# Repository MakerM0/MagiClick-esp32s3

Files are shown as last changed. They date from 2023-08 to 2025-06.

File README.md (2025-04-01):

<p align="center">
    <br>
    
    <br>
</p>
<p align="center">   
    
      
</p>

https://github.com/user-attachments/assets/02206fc1-4ecb-459a-b24e-a9fd3fc22468

# MagiClick S3

This is a versatile, single-button keyboard based on the ESP32-S3 microcontroller, featuring a 0.85-inch color display and customizable functionality, perfect for educational purposes, macro keyboard creation, and desktop decoration.It supports multiple programming languages.

# Specifications

- **Dispaly**: 0.85-inch RGB, 128x128 resolution
- **MCU**: ESP32-S3 , Wi-Fi & BLE
- Main operation via central mechanical buttons, with auxiliary buttons on the sides
- Pluggable mechanical switch design, choice of silent or other types
- speaker
- motion sensor
- Expansion port 
- USB Type-C interface
- Reset button at the bottom
-  RGB LEDs
- more

# Purchase

[Browse products ](https://www.elecrow.com/store/MakerM0)

<a href="https://www.pcbway.com/project/shareproject/MagiClick_S3_Single_506b8396.html">PCB from PCBWay</a>

# Hardware 



| Version | |
| :---: | :---: |
| | |
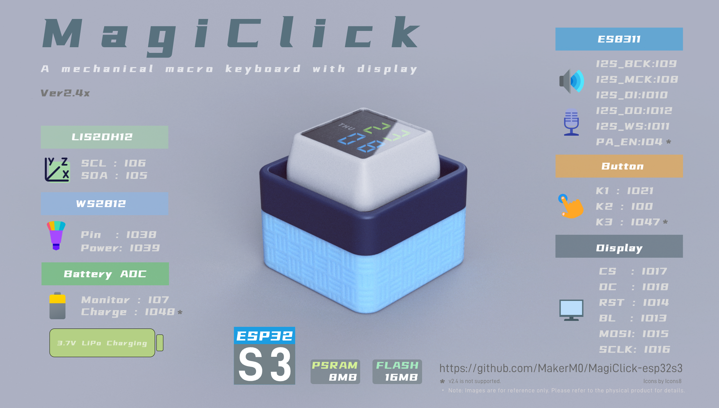
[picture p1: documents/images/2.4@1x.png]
| [2.4](hardware)  |  |
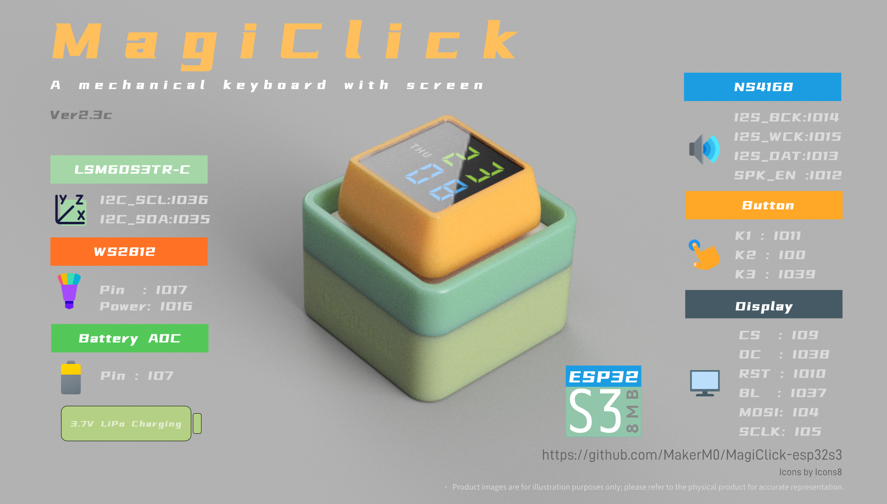
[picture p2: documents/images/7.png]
| [2.3c](hardware)  |  |
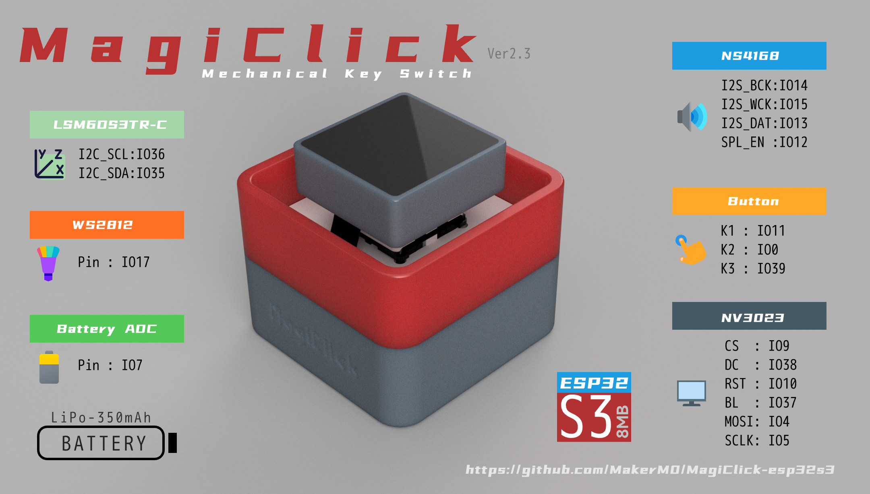
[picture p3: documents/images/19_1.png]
| [2.3b ](hardware) |  |
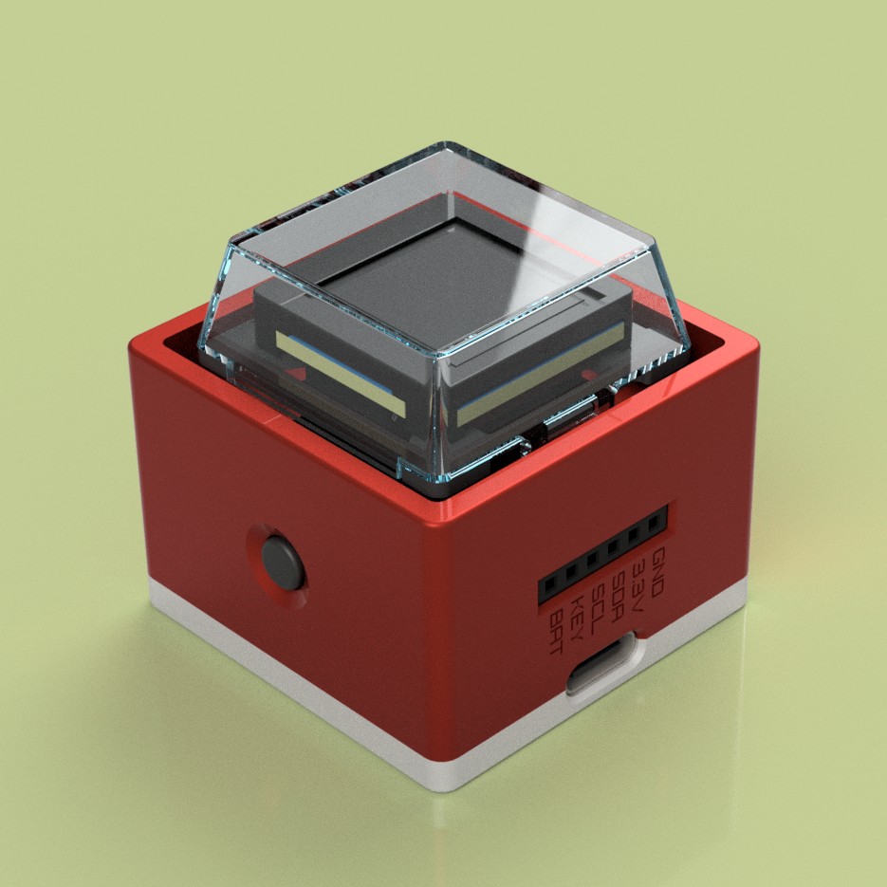
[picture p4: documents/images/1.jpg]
| [2.0](hardware) |  |
| | |

### Difference 

| | v2.0 | v2.3 | v2.4 |
| --- | :---: | :---: | :---: |
| Supported MCU or Module | ESP32-S3-MINI-1-N4R2 or ESP32-S3-MINI-1-N8 | ESP32-S3FN8 | ESP32-S3R8 |
| FLASH | 4MB or 8MB | 8MB | 16MB |
| PSRAM | 2MB or ❌ | ❌ | 8MB |
| Display Driver | GC9107 | NV3023 | NV3023 |
| | GC9107 | NV3023 | NV3023 |
| Battery(with a protection circuit board) | 801230 | 602025 or 802025 | 602025 |
| |  | | |
| Keyboard switch |  |  |  |
| Audio | max98357 | ns4168 | es8311 |
| Microphone | ❌ | ❌ | 1x |
| Motion Sensor | lsm6ds3tr-c | lsm6ds3tr-c | lis2dh12 |

# Software

Supports development using Arduino, CircuitPython, and MicroPython.

The "software" and "firmware" folders in this repository primarily contains the source code related to the hardware version 2.0. 

When you update the circuitpython firmware of the 2.0 hardware to version 9.x, the contents of the 2.3 software [here](https://github.com/MakerM0/MagiClick-S3-Single) folder can then be used by the 2.0 hardware.

For version 2.3, please click  [here](https://github.com/MakerM0/MagiClick-S3-Single).

### Guide

1. Use the Flash Download Tool to burn the Combined .bin in the Firmware folder to the board
2. After rebooting, Then copy the **.uf2** file to a USB stick
3. After rebooting, copy the contents of the softerware folder to the displayed USB stick

 [help](documents/如何下载固件.pdf) 

##### Settings.toml 

modify your wifi information, know the weather key (need to go to the official website to apply) and city

The main button is used to access the function options

The side button or flip button can exit the current function and return to the home page

##### How to add new features

Add the .py file to the app folder

# Mechanical

#### 3D Printings

Makeronline

- [2.3](https://www.makeronline.com/en/model/magiclick%20macropad%20keyboard%20%E7%A5%9E%E5%A5%87%E6%8C%89%E9%92%AE/113241.html)
- [PACKAGING BOX](https://makeronline.com/en/model/product%20packaging%20box/48433.html)
- [PACKAGING BOX_2](https://makeronline.com/en/model/product%20packaging%20box/48433.html)

Makerworld

- [2.0](https://makerworld.com/zh/models/404976#profileId-306794)
- [2.3](https://makerworld.com/zh/models/440612#profileId-346290)
- [2.3](https://makerworld.com/zh/models/584488#profileId-505582)

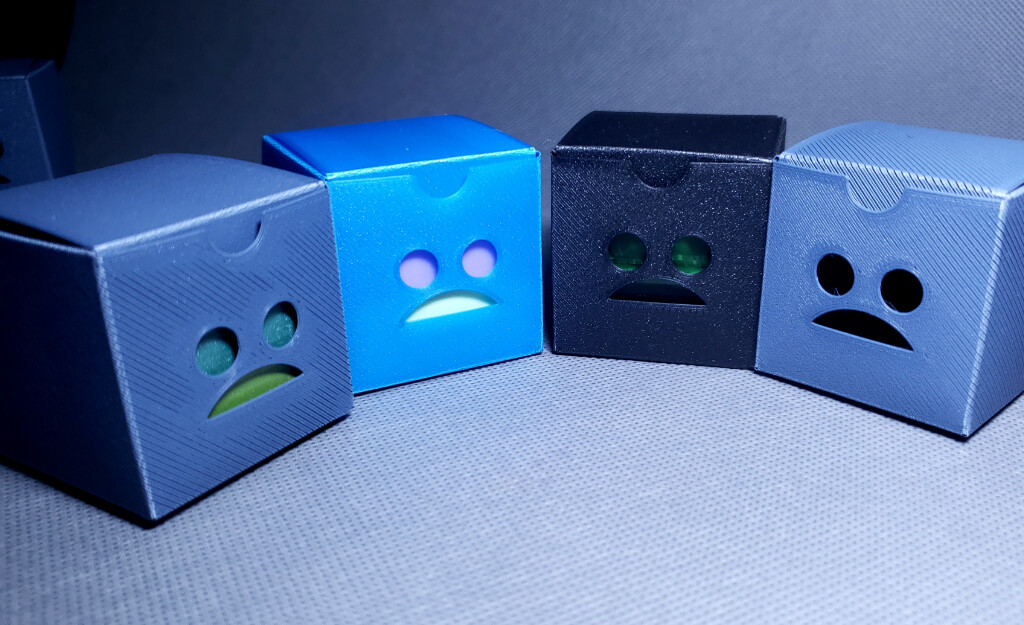
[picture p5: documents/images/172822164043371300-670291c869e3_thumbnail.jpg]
172822164043371300-670291c869e3_thumbnail


## How to contribute

Please use PR to submit contributions

In the **thirdparty** folder, create a project folder according to your own content, the naming needs to be intuitive and easy to understand, and the open source license should be added according to your own wishes

Please add a summary of the contributions in the file **contributer.md**, Add it at the end

## Images

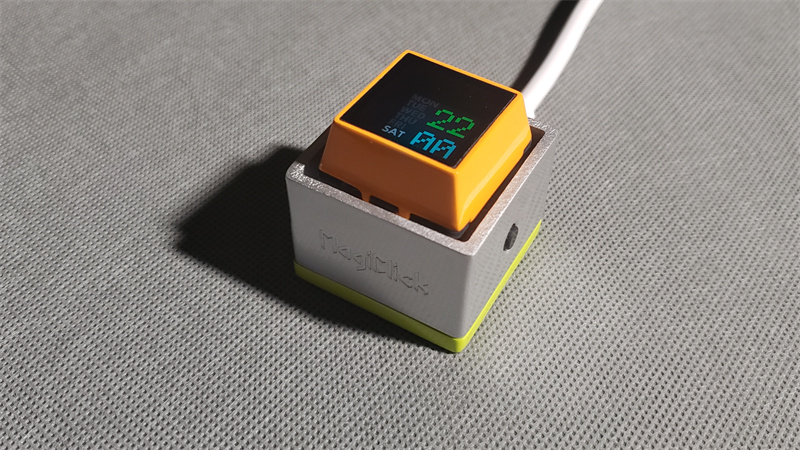
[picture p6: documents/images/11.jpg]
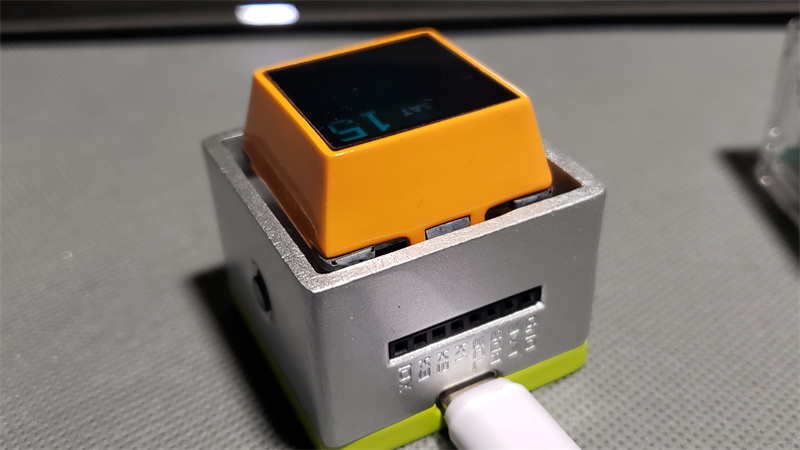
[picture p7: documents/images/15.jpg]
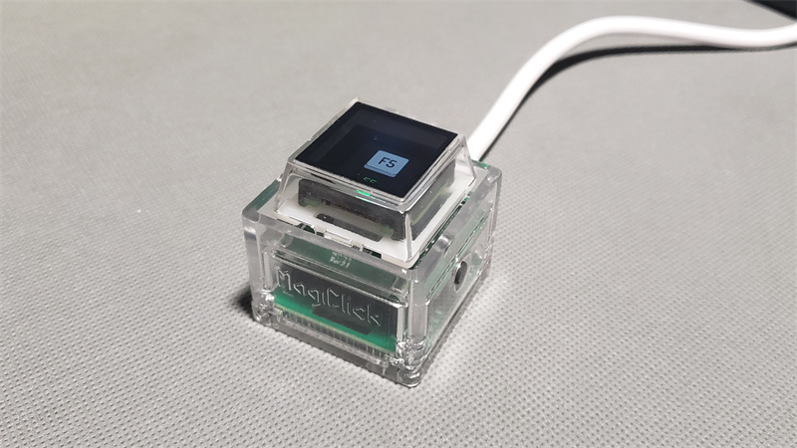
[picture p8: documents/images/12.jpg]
|  |  |  |
| --- | --- | --- |
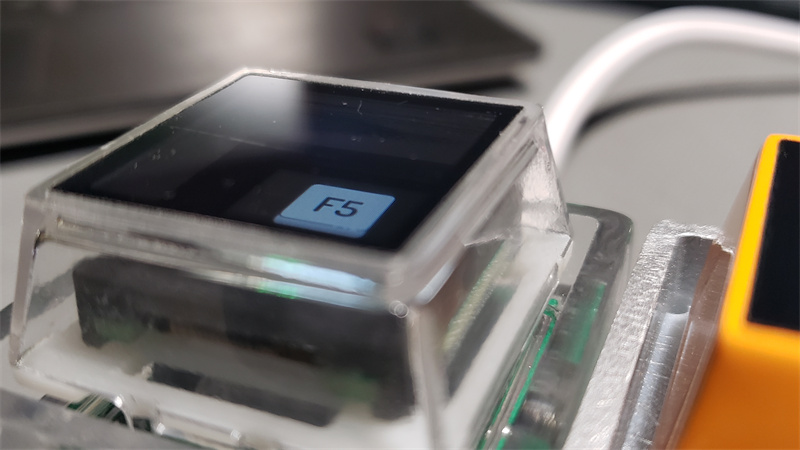
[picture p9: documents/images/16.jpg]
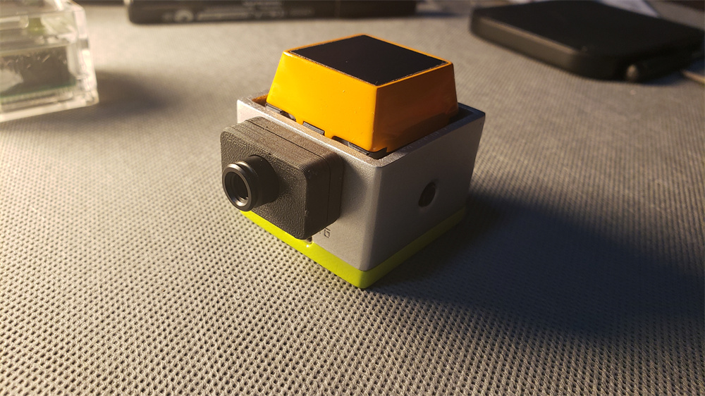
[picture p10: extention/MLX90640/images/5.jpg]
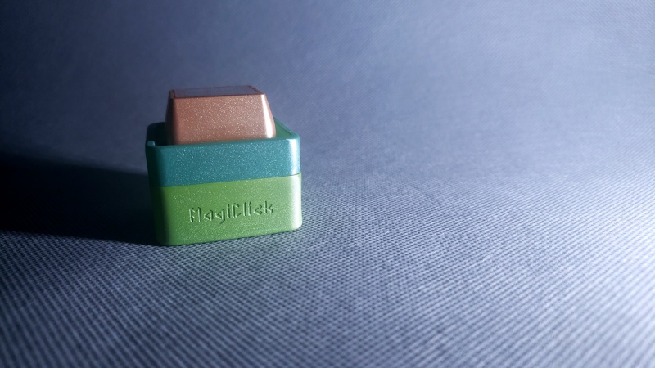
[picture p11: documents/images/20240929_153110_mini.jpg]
20240929_153110_mini
|  |  |  |
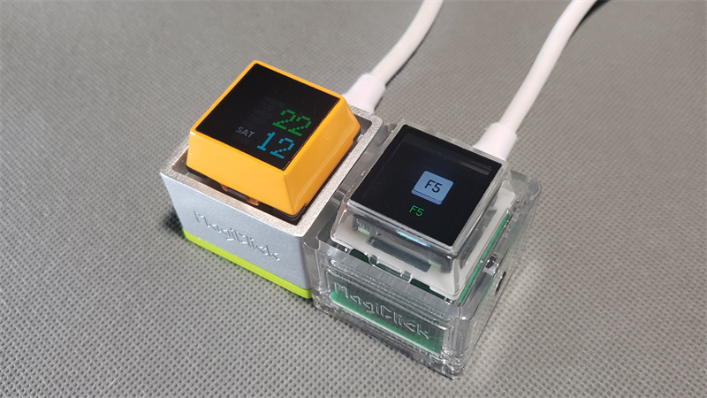
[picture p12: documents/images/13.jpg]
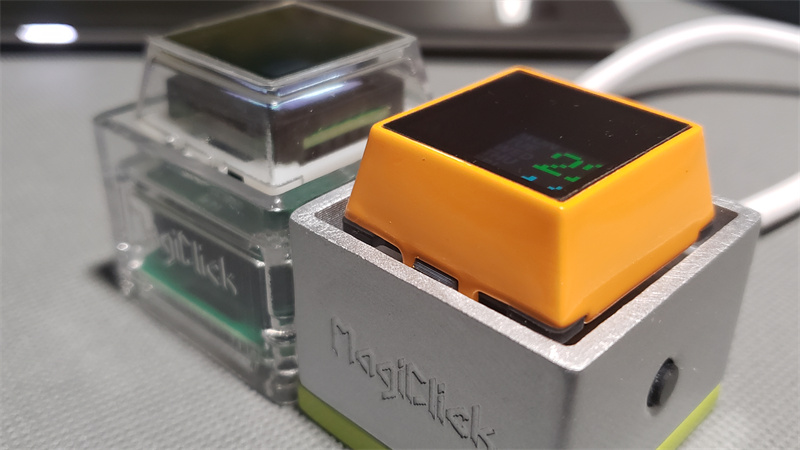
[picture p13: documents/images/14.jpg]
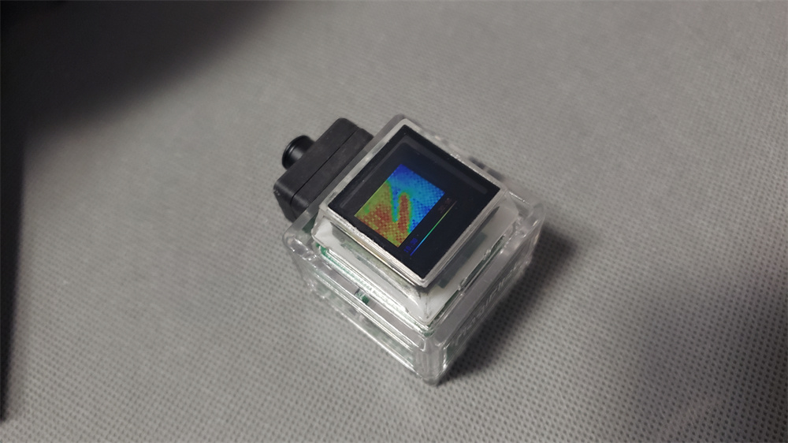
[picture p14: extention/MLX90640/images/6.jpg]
|  |  |  |
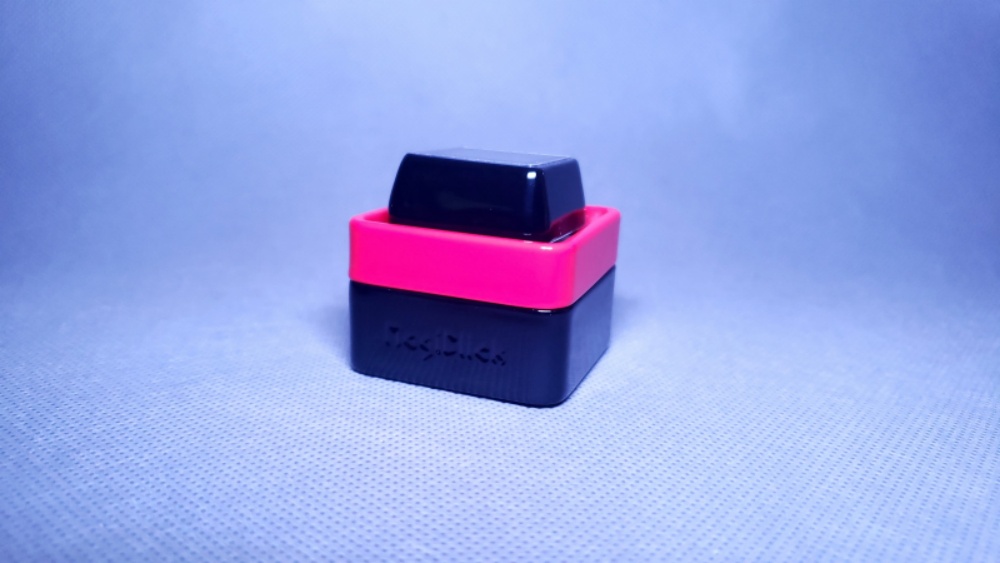
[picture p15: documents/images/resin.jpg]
resin
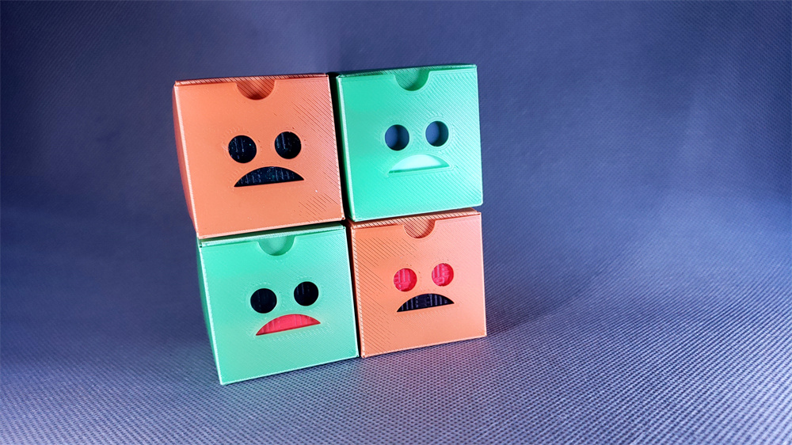
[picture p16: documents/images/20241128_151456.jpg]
| 172822164043371300-670291c869e3_thumbnail |  |  |
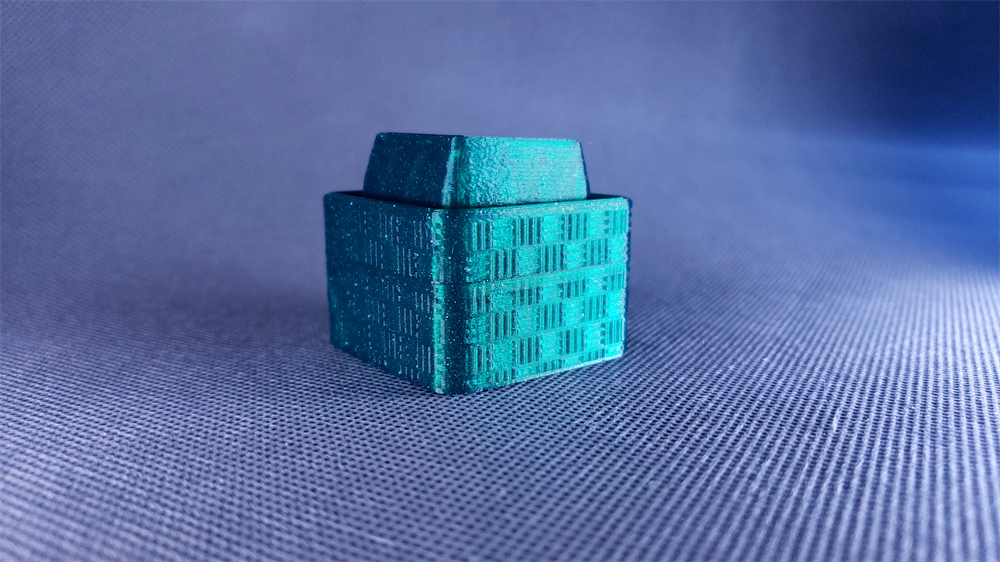
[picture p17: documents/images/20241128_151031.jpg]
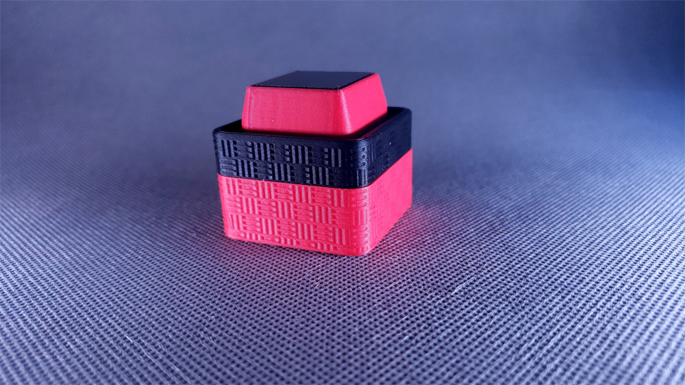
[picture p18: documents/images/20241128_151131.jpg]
|  |  | |

# Extra

The most icons is from https://icons8.com/.

Other resource files come from the internet. 

If there are copyright issues involved, please contact me to delete them.

# License

(documents/hardware/mechanical)[Creative Commons — Attribution-NonCommercial-ShareAlike 4.0 International — CC BY-NC-SA 4.0](https://creativecommons.org/licenses/by-nc-sa/4.0/)

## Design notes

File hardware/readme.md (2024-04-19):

## 2.3b

- The power path has been modified, and the switch can fully control the power supply on and off

- The 0402 package is fully adopted, which greatly reduces the total PCB area

- The main controller replaces the original module in the form of a chip

- The audio chip was replaced

**Click on the image below and you can make it directly**

<a href="https://www.pcbway.com/project/shareproject/MagiClick_S3_Single_506b8396.html">PCB from PCBWay</a>

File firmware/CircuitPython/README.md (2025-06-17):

# 1

burn the bin file from the bootloader to address 0

# 2

restart the device and drag the uf2 file into the USB drive

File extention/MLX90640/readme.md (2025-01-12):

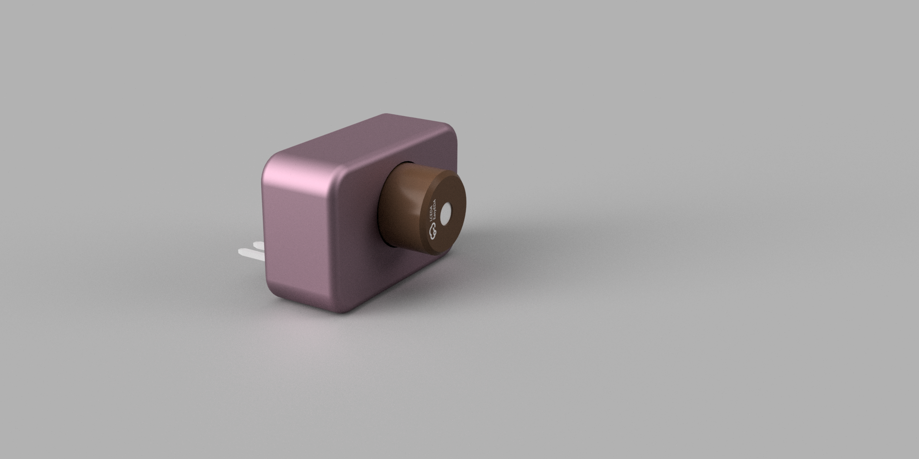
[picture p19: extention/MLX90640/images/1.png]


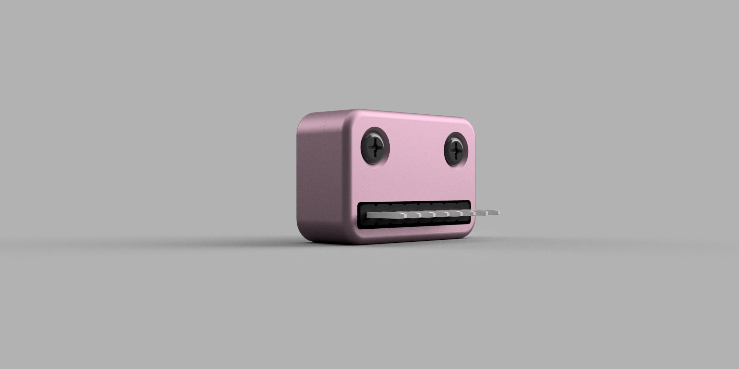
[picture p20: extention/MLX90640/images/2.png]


# MLX90640

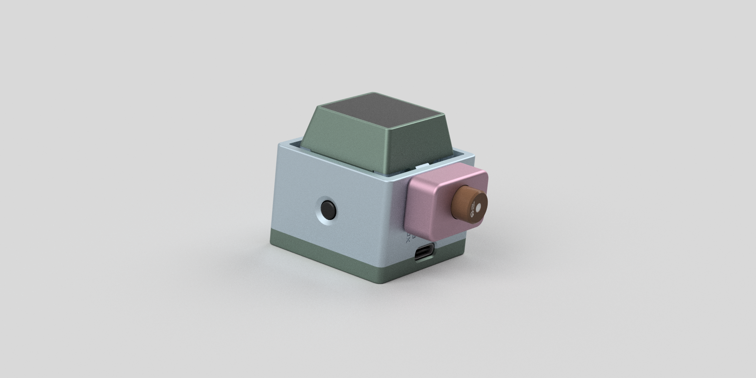
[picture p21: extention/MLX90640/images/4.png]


## SUPPORT

- MagiClick 2.0 PCB

## BOM

| No.  | Quantity | Designator | Footprint | Manufacturer Part | Manufacturer | Supplier | Supplier Part | Value | Comment | JLCPCB Part Class |
| ---- | --- | --- | --- | --- | --- | --- | --- | ----- | --- | --- |
| 1 | 1 | C1 | C0603 | CL10A106KP8NNNC | SAMSUNG(三星) | LCSC | C19702 | 10uF  | 10uF | Basic Part |
| 2 | 1 | C2 | C0603 | 0603B104K500NT | FH(风华) | LCSC | C30926 | 100nF | 100nF | 扩展库 |
| 3 | 1 | U1 | TO-39-4_MELEXIS_MLX90640 | **MLX90640ESF-BAB-000-TU** | Melexis(比利时迈来芯) | LCSC | C488251 | | MLX90640ESF-BAB-000-TU | Extended Part |
| 4 | 1 | U203 | HDR-TH_8P-P2.54-V-M | PZ254V-11-08P | XFCN(兴飞) | LCSC | C492407 | | PZ254V-11-08P | Extended Part |

## PCB

1.6mm

## 304不锈钢自攻螺丝十字沉头螺丝

M2*8   2

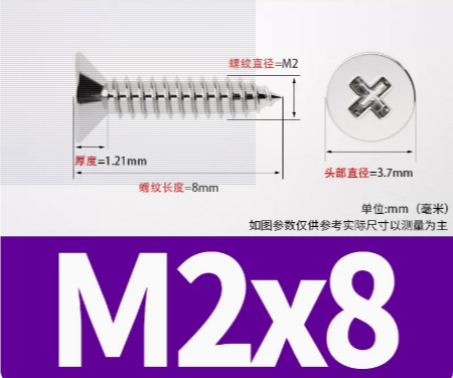
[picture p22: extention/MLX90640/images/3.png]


## images





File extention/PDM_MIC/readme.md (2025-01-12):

# PDM_MIC

Due to the limitations of the current 2.3 version hardware, in order to use this module, it is necessary to remove the motion sensor and its associated components.

## SUPPORT

- MagiClick 2.3c PCB

## BOM

-  [BOM.xlsx](BOM.xlsx) 
- JS05B-04P-030-3-4

## PCB

thickness: 1.6mm

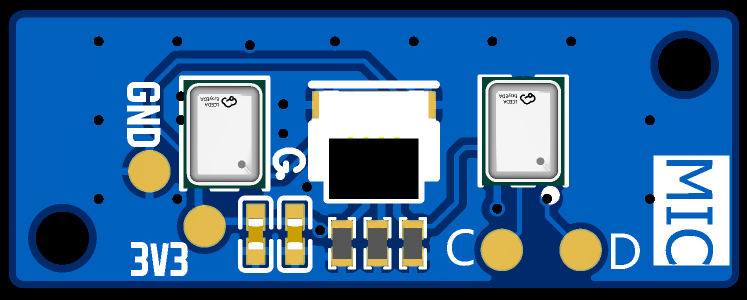
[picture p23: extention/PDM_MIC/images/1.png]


## GUIDE

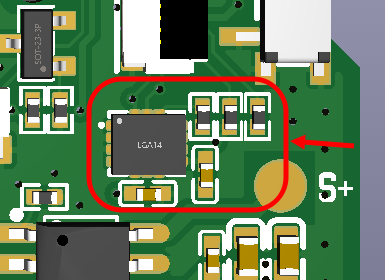
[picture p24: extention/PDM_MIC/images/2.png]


Remove the components within the red box.

## images

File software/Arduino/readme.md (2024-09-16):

# Ported Source

### esp32_gfx_dino

[wasm-embedded/arduino/esp32_gfx_dino at master · wuhanstudio/wasm-embedded (github.com)](https://github.com/wuhanstudio/wasm-embedded/tree/master/arduino/esp32_gfx_dino)





### TinyFlap

Code ported from [soelvberg/TinyFlap: A Flappy Bird like game for micro controller with 128x128 TFT display. (github.com)](https://github.com/soelvberg/TinyFlap)

Please use [PlatformIO](https://platformio.org/platformio-ide) for compilation and development

Flashing this firmware may overwrite the previous python file, please make a backup

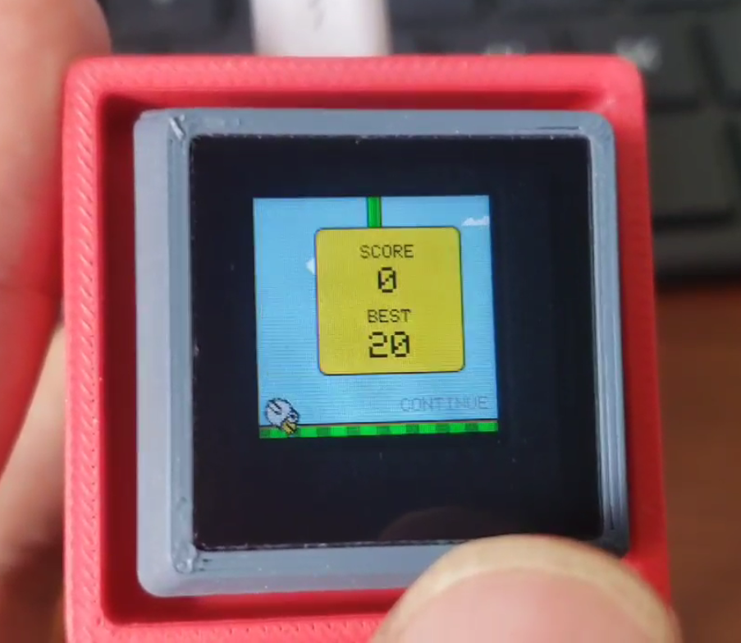
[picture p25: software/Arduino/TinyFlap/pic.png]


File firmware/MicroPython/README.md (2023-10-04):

# Thanks to the following friends for their contributions

### The contents under the jd3096 folder are from [jd3096-mpy](https://github.com/jd3096-mpy)

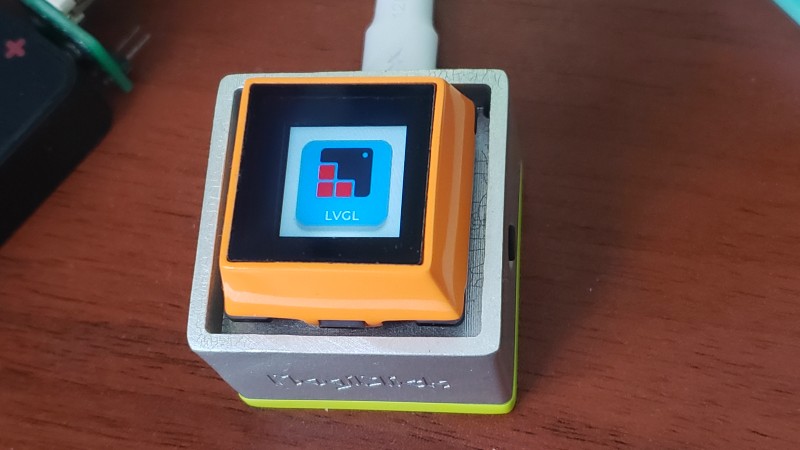
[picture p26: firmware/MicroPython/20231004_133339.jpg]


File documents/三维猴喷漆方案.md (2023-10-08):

# 使用LEDO 6060 材质官方喷漆

### 底盖

喷漆-亮光-浅绿色  

### 外壳

喷漆-亮光-银色

### 玻璃罩

喷漆-亮光-橙色

# EVA配色

绿色 （100，181，26）

紫色（132，85，165）

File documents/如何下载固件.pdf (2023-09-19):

# 如何给神奇按钮下载固件

https://github.com/MakerM0/MagiClick-esp32s3

# 1、进入esp32-S3芯片的下载模式

在插入usb的情况下，按住左侧按钮不放，然后使用镊子按下底部的复位按钮，然后会发现电脑的设备 管理器出现了串口（记住自己的端口号），此时可以松开左侧按键

# 2、烧写bootload

使用乐鑫官方的flash download tool工具，可从官网或github仓库的tool文件夹找到

按箭头所示操作即可

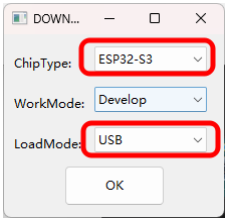
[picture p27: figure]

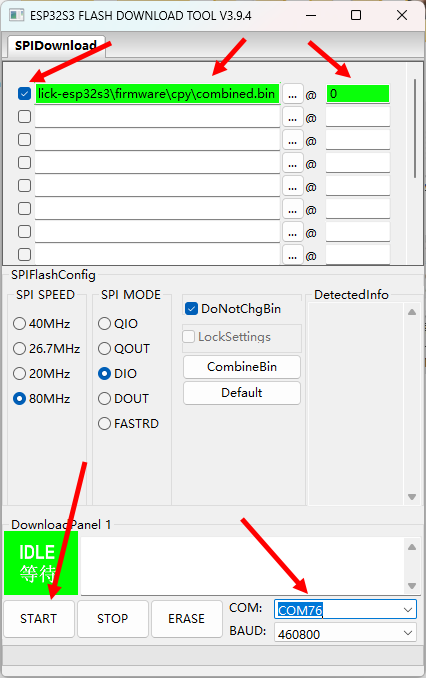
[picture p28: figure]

下载成功后出现

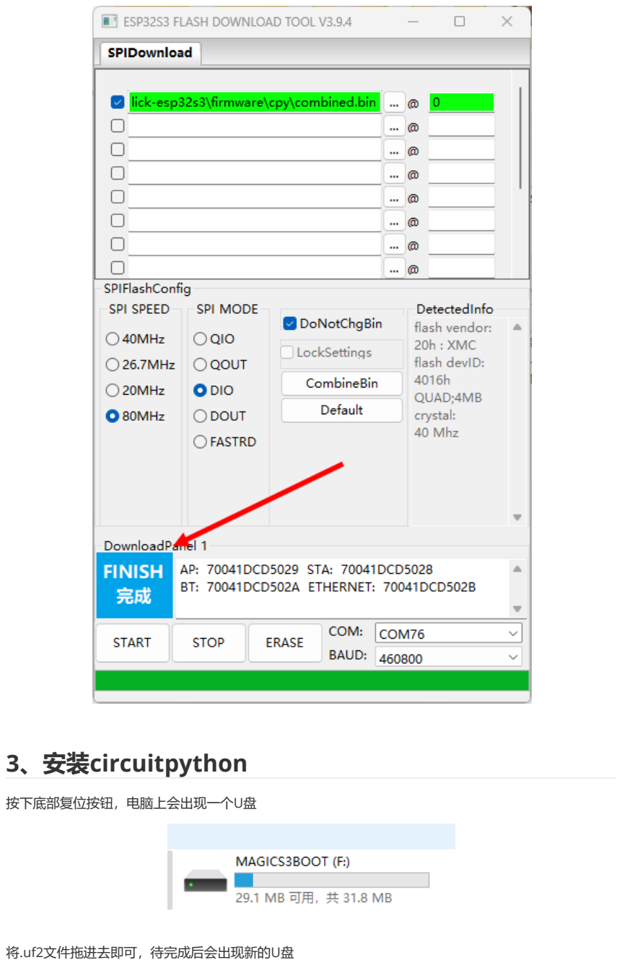
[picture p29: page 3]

# 3、安装circuitpython

按下底部复位按钮，电脑上会出现一个U盘

将.uf2文件拖进去即可，待完成后会出现新的U盘

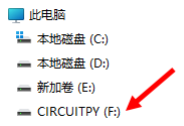
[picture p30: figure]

# 4、复制软件包到U盘

将github上software里面的内容复制到U盘即可完成功能更新

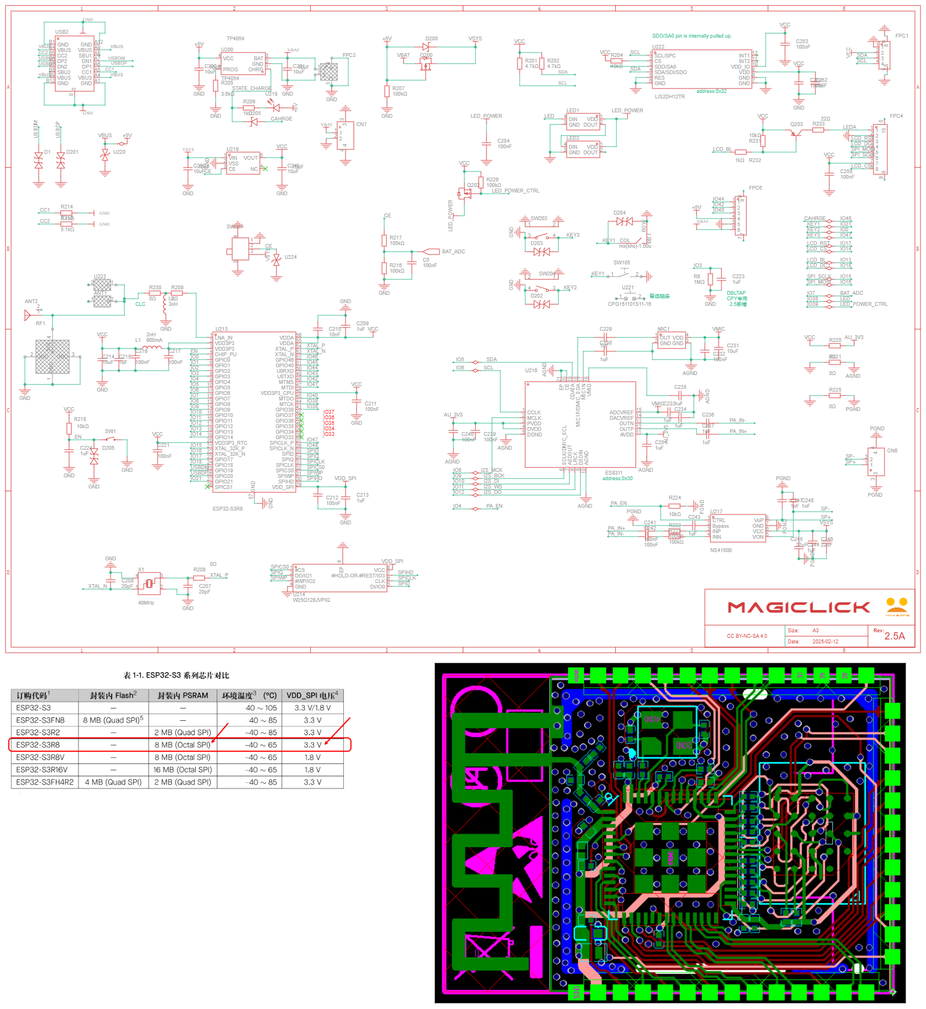
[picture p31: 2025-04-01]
hardware/2.5/SCH_2.5A.png

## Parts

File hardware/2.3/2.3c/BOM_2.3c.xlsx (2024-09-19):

Comment | Designator | Footprint | Supplier Part | Quantity | Description | Layer | JLCPCB Part Class
100nF | C5,C9,C202,C203,C211,C212,C216,C217,C221 | C0402 | C1525 | 9 | 容值:100nF;精度:±10%;额定电压:16V;材质(温度系数):X7R; | B | Basic Part,基础库
10uF | C200,C201,C214 | C0603 | C19702 | 3 | 容值:10uF;精度:±10%;额定电压:10V;材质(温度系数):X5R; | B | Basic Part
1uF | C204,C205 | C0603 | C15849 | 2 | 温度系数:X5R;精度:±10%;额定电压:50V;容值:1uF; | B | Basic Part
20pF | C207,C208 | C0402 | C1554 | 2 | 容值:20pF;精度:±5%;额定电压:50V;材质(温度系数):C0G; | B | 基础库
1uF | C209,C213,C215,C223,C224,C228 | C0402 | C52923 | 6 | 容值:1uF;精度:±10%;额定电压:25V;材质(温度系数):X5R; | B | 基础库
10nF | C210 | C0402 | C15195 | 1 | 容值:10nF;精度:±10%;额定电压:50V;材质(温度系数):X7R; | B | 基础库
22uF | C226,C227 | C0603 | C59461 | 2 | 容值:22uF;精度:±20%;额定电压:6.3V;材质(温度系数):X5R; | B | Basic Part
HC-FPC-05-09-12RLTAG | CN4 | CONN-SMD_12P-P0.50_HCTL_HC-FPC-05-09-12RLTAG | C5213751 | 1 | 间距:0.5mm;触点数量:12P;锁定特性:翻盖式;安装类型:卧贴;触点类型:下接; | B | 扩展库
PESDNC2FD3V3B | D1,D201,D202,D203,D204 | DFN1006-2L-BI | C492728 | 5 |  | B | 扩展库
1N5819WS | D200 | SOD-323_L1.8-W1.3-LS2.5-RD | C191023 | 1 | 直流反向耐压(Vr):40V;平均整流电流(Io):1A;正向压降(Vf):600mV@1A; | B | Basic Part
HC-FPC-05-09-4RLTAG | FPC1 | FPC-SMD_4P-P0.50_HC-FPC-05-09-4RLTAG | C5213746 | 1 | 锁定特性:翻盖式;触点类型:双侧触点/上下接;触点数量:4P;间距:0.5mm;安装类型:卧贴;工作温度范围:-55℃~+85℃;焊接温度(最大值):-; | B | 扩展库
2nH | L1 | L0402 | C18216 | 1 | 电感值:2nH;精度:-;额定电流:900mA;饱和电流(Isat):-;直流电阻(DCR):90mΩ; | B | Extended Part
XL-3216SURC-FB | LED201 | LED1206-RD_RED_LTST-C230CKT | C3646938 | 1 | 灯头类型:-;发光颜色:红色;正向电压(VF):1.8V~2.1V;功率:60mW;正向电流:5mA;主波长:617nm~627nm;二极管配置:-;透镜颜色:透明透镜;色温:-;发光强度:100mcd~120mcd;发光角度:120°;载带方式:反贴;工作温度:-; | B | 扩展库
SK6812MINI-E | LED202 | LED-SMD_L3.2-W2.8-TR | C5149201 | 1 |  | B | Extended Part
CPG151101S11-16 | MX1 | cherrymx(khs)-1.00u | C5156480 | 1 | 轴类型:-;工作电压:2V~12V;操作力:-;触底力:-;触发行程:-;总行程:-;针脚数:-;机械寿命:-;工作温度:-; | B | Extended Part
AO3401A | Q200 | SOT-23_L2.9-W1.3-P1.90-LS2.4-BR | C15127 | 1 | 类型:P沟道;漏源电压(Vdss):30V;连续漏极电流(Id):4A;功率(Pd):1.4W;导通电阻(RDS(on)@Vgs,Id):44mΩ@10V,4.3A;阈值电压(Vgs(th)@Id):1.3V@250A; | B | Basic Part
SS8050 | Q201 | SOT-23-3_L2.9-W1.3-P1.90-LS2.4-BR | C2150 | 1 | 集电极电流(Ic):1.5A;功率(Pd):300mW;晶体管类型:NPN;集射极击穿电压(Vceo):25V; | B | BasicPart
1MΩ | R8 | R0402 | C26083 | 1 | 电阻类型:厚膜电阻;阻值:1MΩ;精度:±1%;功率:62.5mW;最大工作电压:50V;温度系数:±100ppm/℃; | B | Basic Part
10kΩ | R201,R202,R204,R211,R218 | R0402 | C25744 | 5 | 电阻类型:厚膜电阻;阻值:10kΩ;精度:±1%;功率:62.5mW;最大工作电压:50V;温度系数:±100ppm/℃; | B | Basic Part
5.1kΩ | R205,R214,R215 | R0402 | C25905 | 3 | 电阻类型:厚膜电阻;阻值:5.1kΩ;精度:±1%;功率:62.5mW;最大工作电压:50V;温度系数:±100ppm/℃;,阻值:5.1kΩ;精度:±1%;功率:62.5mW;温度系数:±100ppm/℃;电阻类型:厚膜电阻; | B | Basic Part
1kΩ | R206,R212 | R0402 | C11702 | 2 | 电阻类型:厚膜电阻;阻值:1kΩ;精度:±1%;功率:62.5mW;最大工作电压:50V;温度系数:±100ppm/℃; | B | Basic Part
100kΩ | R207,R216,R217,R219 | R0402 | C25741 | 4 | 电阻类型:厚膜电阻;阻值:100kΩ;精度:±1%;功率:62.5mW;最大工作电压:50V;温度系数:±100ppm/℃; | B | Basic Part
0Ω | R208,R209 | R0402 | C17168 | 2 | 电阻类型:厚膜电阻;阻值:0Ω;精度:±1%;功率:62.5mW;最大工作电压:50V;温度系数:±800ppm/℃; | B | 基础库
22Ω | R213 | R0402 | C25092 | 1 | 电阻类型:厚膜电阻;阻值:22Ω;精度:±1%;功率:62.5mW;最大工作电压:50V;温度系数:±100ppm/℃; | B | Basic Part
TSA010A2026B | SW1 | SW-SMD_L4.0-W3.0-LS5.0 | C2888420 | 1 | 触点电流:50mA;额定电压(AC):-;额定电压(DC):12V;安装方式:立贴;按钮形状:圆形按钮;开关长度:3.9mm;开关宽度:3mm;开关高度:2mm; | B | Extended Part
TS24CA 250gf 013 | SW203,SW204 | SW-SMD_L4.7-W3.5-P3.35-EH | C5373430 | 2 | 电路结构:单刀单掷;按钮形状:矩形按钮;作用力:250gf;安装方式:卧贴;开关长度:4.55mm;开关宽度:1.8mm;开关高度:3.5mm;带支架:不带;触点电流:50mA;额定电压(AC):-;额定电压(DC):12V;额定功率:0.6W;绝缘电阻:100MΩ;带灯:无;机械寿命:3万次; | B | 扩展库
MSK12C02 | SW205 | SW-TH_MSK12C02 | C431540 | 1 | 电路结构:单刀双掷;安装方式:卧贴;开关颜色:-;额定电流(DC):50mA;额定电压(DC):12V;额定电流(AC):-;额定电压(AC):-;机械寿命:1万次; | B | 扩展库
TP4054 | U200 | SOT-23-5_L2.9-W1.6-P0.95-LS2.8-BR | C5381776 | 1 | 电源电压:4V~9V;最大充电电流:800mA;电池类型:锂离子/聚合物;电池节数:1; | B | Extended Part
LSM6DS3TR-C | U201 | LGA-14_L3.0-W2.5-P0.50-TL | C967633 | 1 |  | B | Extended Part
AP2112K-3.3TRG1 | U202 | SOT-25-5_L2.9-W1.6-P0.95-LS2.8-BL | C51118 | 1 | 输出类型:固定;输出极性:正;最大输入电压:6V;输出电压:3.3V;输出电流:600mA;电源纹波抑制比(PSRR):65dB@(100Hz,1kHz); | B | Extended Part
ESP32-S3FN8 | U205 | QFN-56_L7.0-W7.0-P0.40-TL-EP4.0 | C2913196 | 1 |  | B | 扩展库
NS4168 | U207 | ESOP-8_L4.9-W3.9-P1.27-LS6.0-BL-EP-1 | C9900042517 | 1 |  | B
AN2051-245 | U208 | ANT2051 | C99727 | 1 | 小体积，高增益，WIFI，蓝牙，zigBee 2.4G天线 | B | Extended Part
USB-TYPE-C-018 | USB2 | usb-c_smd-type-c-31-m-12 | C2927038 | 1 | 连接器类型:Type-C;标准:-;公母:母座;触点数量:16;端口数量:1;安装方式:卧贴;额定电流 - 电源:3A;工作温度范围:-25~+85; | B | Extended Part
40MHz | X1 | CRYSTAL-SMD_4P-L3.2-W2.5-BL | C5444549 | 1 | 晶振类型:贴片晶振;频率:40MHz;常温频差:±10ppm;外接负载电容:15pF;频率稳定度(全温):±20ppm; | B | Extended Part

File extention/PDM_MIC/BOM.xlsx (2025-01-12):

Comment | Designator | Footprint | Supplier Part | Quantity | Manufacturer | Manufacturer Part
1uF | C106 | C0402 | C52923 | 1 | SAMSUNG(三星) | CL05A105KA5NQNC
100nF | C107 | C0402 | C1525 | 1 | SAMSUNG(三星) | CL05B104KO5NNNC
PESDNC2FD3V3B | D1,D2,D3 | DFN1006-2L-BI | C492728 | 3 | Prisemi(芯导) | PESDNC2FD3V3B
HC-FPC-05-09-4RLTAG | FPC1 | FPC-SMD_4P-P0.50_HC-FPC-05-09-4RLTAG | C5213746 | 1 | HCTL(华灿天禄) | HC-FPC-05-09-4RLTAG
MMICT390200012 | MIC2 | MIC-SMD_5P-L3.5-W2.7-TL_MMICT390200012 | C3171752 | 1 | TDK InvenSense(应美盛) | MMICT390200012

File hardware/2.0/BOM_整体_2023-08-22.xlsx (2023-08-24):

No. | Quantity | Designator | Footprint | Manufacturer Part | Manufacturer | Supplier | Supplier Part | Value | Comment | JLCPCB Part Class
1 | 5 | C1,C6,C7,C200,C201 | C0603 | CL10A106KP8NNNC | SAMSUNG(三星) | LCSC | C19702 | 10uF | 10uF | Basic Part
2 | 6 | C2,C5,C9,C202,C203,C300 | C0603 | CC0603KRX7R9BB104 | YAGEO(国巨) | LCSC | C14663 | 100nF | 100nF | Basic Part
3 | 6 | C8,C10,C11,C204,C205,C301 | C0603 | CL10A105KB8NNNC | SAMSUNG(三星) | LCSC | C15849 | 1uF | 1uF | Basic Part
4 | 1 | D200 | SOD-323_L1.8-W1.3-LS2.5-RD | 1N5819WS | Hottech(合科泰) | LCSC | C191023 |  | 1N5819WS | Basic Part
5 | 6 | H1,H2,H3,H4,H200,H201 | HDR-TH_4P-P2.54-V-F | 2.54-1*4P母 | BOOMELE(博穆精密) | LCSC | C2718488 |  | 2.54-1*4P母 | Extended Part
6 | 6 | H202,H203,H204,H205,H300,H301 | HDR-TH_4P-P2.54-V-M | DZ254R-11-04-63 | DEALON(德艺隆) | LCSC | C2935910 |  | DZ254R-11-04-63 | Extended Part
7 | 2 | LED1,LED2 | LED-SMD_4P-L1.6-W1.5_XL-1615RGBC-WS2812B | XL-1615RGBC-WS2812B | XINGLIGHT(成兴光) | LCSC | C5349954 |  | XL-1615RGBC-WS2812B | Extended Part
8 | 1 | Q200 | SOT-23_L2.9-W1.3-P1.90-LS2.4-BR | AO3401A | AOS | LCSC | C15127 |  | AO3401A | Basic Part
9 | 1 | Q300 | SOT-23-3_L2.9-W1.3-P1.90-LS2.4-BR | SS8050 | CJ（江苏长电/长晶） | LCSC | C2150 |  | SS8050 | BasicPart
10 | 1 | R1 | R0603 | WR06X6343FTL | Walsin(华新科) | LCSC | C334826 | 634kΩ | 634kΩ | Extended Part
11 | 2 | R2,R207 | R0603 | 0603WAF1003T5E | UNI-ROYAL(厚声) | LCSC | C25803 | 100kΩ | 100kΩ | Basic Part
12 | 2 | R3,R4 | R0603 | 0603WAF5101T5E | UNI-ROYAL(厚声) | LCSC | C23186 | 5.1kΩ | 5.1kΩ | Basic Part
13 | 2 | R5,R6 | R0603 | 0603WAF2003T5E | UNI-ROYAL(厚声) | LCSC | C25811 | 200kΩ | 200kΩ | Basic Part
14 | 7 | R7,R201,R202,R203,R204,R205,R302 | R0603 | 0603WAF1002T5E | UNI-ROYAL(厚声) | LCSC | C25804 | 10kΩ | 10kΩ | Basic Part
15 | 1 | R8 | R0603 | 0603WAF1004T5E | UNI-ROYAL(厚声) | LCSC | C22935 | 1MΩ | 1MΩ | 基础库
16 | 2 | R206,R301 | R0603 | 0603WAF1001T5E | UNI-ROYAL(厚声) | LCSC | C21190 | 1kΩ | 1kΩ | Basic Part
17 | 1 | R300 | R0603 | 0603WAF200JT5E | UNI-ROYAL(厚声) | LCSC | C22950 | 20Ω | 20Ω | Basic Part
18 | 1 | SW1 | SW-SMD_L4.0-W3.0-LS5.0 | TSA010A2026B | BZCN(博众电气) | LCSC | C2888420 |  | TSA010A2026B | Extended Part
19 | 1 | SW2 | SW-SMD_MS-22D28-G020 | MS-22D28-G020 | G-Switch(品赞) | LCSC | C963205 |  | MS-22D28-G020 | Extended Part
20 | 2 | SW200,SW202 | SW-TH_ST-1109-3-5 | TS-1091B-A4B3-D2 | Yuandi(元迪) | LCSC | C557910 |  | TS-1091B-A4B3-D2 | Extended Part
21 | 1 | SW201 | 凯华矮轴 复合 热插拔 | CPG135001S30 | Kailh(凯华) | LCSC | C5333465 |  | CPG135001S30 | Extended Part
22 | 1 | U1 | TQFN-16_L3.0-W3.0-P0.50-BL-EP1.5 | MAX98357AETE+T | ADI(亚德诺)/MAXIM(美信) | LCSC | C910544 |  | MAX98357AETE+T | Extended Part
23 | 1 | U2 | BULETM-SMD_ESP32-S3-MINI-1-N8 | ESP32-S3-MINI-1-N4R2 | ESPRESSIF(乐鑫) | LCSC | C3013941 |  | ESP32-S3-MINI-1-N4R2 | Extended Part
24 | 1 | U200 | TSOT-23-5_L2.9-W1.6-P0.95-LS2.8-BR | TP4054 | UMW(友台半导体) | LCSC | C668215 |  | TP4054 | Extended Part
25 | 1 | U201 | LGA-14_L3.0-W2.5-P0.50-TL | LSM6DS3TR-C | ST(意法半导体) | LCSC | C967633 |  | LSM6DS3TR-C | Extended Part
26 | 1 | U202 | SOT-25-5_L2.9-W1.6-P0.95-LS2.8-BL | AP2112K-3.3TRG1 | DIODES(美台) | LCSC | C51118 |  | AP2112K-3.3TRG1 | Extended Part
27 | 1 | U203 | HDR-TH_8P-P2.54-H-F-W10.3-N | DW254W-11-08-85 | DEALON(德艺隆) | LCSC | C2935998 |  | DW254W-11-08-85 | Extended Part
28 | 1 | U300 | TFT_0.85inch_128*128 |  |  |  |  |  | 0.85inch-TFT
29 | 1 | USB1 | USB-C-SMD_SHOU_TYPE-C-16P-CB1.6 | TYPE-C 16P CB1.6 073 | SHOU HAN(首韩) | LCSC | C2906290 |  | TYPE-C 16P CB1.6 073 | Extended Part

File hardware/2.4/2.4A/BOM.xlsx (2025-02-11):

Comment | Designator | Footprint | Supplier Part | Quantity | Manufacturer | Manufacturer Part
100nF | C5,C203,C211,C212,C216,C217,C221,C232,C239,C240,C241,C242,C253,C254 | C0402 | C1525 | 14 | SAMSUNG(三星) | CL05B104KO5NNNC
10uF | C200,C201,C214,C231,C249,C250,C252 | C0402 | C2846677 | 7 | FH(风华) | 0402X106M100NT
20pF | C207,C208 | C0402 | C1554 | 2 | FH(风华) | 0402CG200J500NT
1uF | C209,C213,C215,C224,C229,C230,C233,C234,C235,C236,C237,C243,C244,C251 | C0402 | C52923 | 14 | SAMSUNG(三星) | CL05A105KA5NQNC
10nF | C210 | C0402 | C15195 | 1 | SAMSUNG(三星) | CL05B103KB5NNNC
22uF | C245,C246 | C0603 | C59461 | 2 | SAMSUNG(三星) | CL10A226MQ8NRNC
1nF | C247,C248 | C0402 | C1523 | 2 | FH(风华) | 0402B102K500NT
HC-FPC-05-09-12RLTAG | CN4 | CONN-SMD_12P-P0.50_HCTL_HC-FPC-05-09-12RLTAG | C5213751 | 1 | HCTL(华灿天禄) | HC-FPC-05-09-12RLTAG
PESDNC2FD3V3B | D1,D201,D202,D203,D204 | DFN1006-2L-BI | C492728 | 5 | Prisemi(芯导) | PESDNC2FD3V3B
1N5819WS | D200,D205 | SOD-323_L1.8-W1.3-LS2.5-RD | C191023 | 2 | Hottech(合科泰) | 1N5819WS
BSMD0603L-100 | F1 | F0603 | C2757929 | 1 | BHFUSE(佰宏) | BSMD0603L-100
HC-FPC-05-09-4RLTAG | FPC1 | FPC-SMD_4P-P0.50_HC-FPC-05-09-4RLTAG | C5213746 | 1 | HCTL(华灿天禄) | HC-FPC-05-09-4RLTAG
1.25-2PS | FPC2,FPC3 | CONN-SMD_2P-P1.25_DEALON_1.25-2PS | C2904989 | 2 | DEALON(德艺隆) | 1.25-2PS
2nH | L1 | L0402 | C18216 | 1 | muRata(村田) | LQG15HS2N0S02D
SK6805-EC15 | LED4,LED5 | LED-SMD_4P-L1.5-W1.5-BL | C2890035 | 2 | 欧思科光电 | SK6805-EC15
ZTS6216 | MIC1 | MIC-SMD_4P-L2.8-W1.9-P1.84-TL | C481302 | 1 | ZILLTEK(钰太) | ZTS6216
AO3401A | Q200,Q202 | SOT-23_L2.9-W1.3-P1.90-LS2.4-BR | C15127 | 2 | AOS | AO3401A
SS8050 | Q201 | SOT-23-3_L2.9-W1.3-P1.90-LS2.4-BR | C2150 | 1 | CJ（江苏长电/长晶） | SS8050
4.7kΩ | R201,R202 | R0402 | C25900 | 2 | UNI-ROYAL(厚声) | 0402WGF4701TCE
10kΩ | R204,R205,R211,R218,R224 | R0402 | C25744 | 5 | UNI-ROYAL(厚声) | 0402WGF1002TCE
1kΩ | R206,R212 | R0402 | C11702 | 2 | UNI-ROYAL(厚声) | 0402WGF1001TCE
100kΩ | R207,R216,R217,R222,R223,R226 | R0402 | C25741 | 6 | UNI-ROYAL(厚声) | 0402WGF1003TCE
0Ω | R208,R209,R220,R221,R225 | R0402 | C17168 | 5 | UNI-ROYAL(厚声) | 0402WGF0000TCE
22Ω | R213 | R0402 | C25092 | 1 | UNI-ROYAL(厚声) | 0402WGF220JTCE
5.1kΩ | R214,R215 | R0402 | C25905 | 2 | UNI-ROYAL(厚声) | 0402WGF5101TCE
KH-IPEX-K501-29 | RF1 | ANT-SMD_KH-IPEX-K501-29 | C411563 | 1 | kinghelm(金航标) | KH-IPEX-K501-29
TSA010A2026B | SW1 | SW-SMD_L4.0-W3.0-LS5.0 | C2888420 | 1 | BZCN(博众电气) | TSA010A2026B
TS24CA 250gf 013 | SW203,SW204 | SW-SMD_L4.7-W3.5-P3.35-EH | C5373430 | 2 | SHOU HAN(首韩) | TS24CA 250gf 013
MSK12C02 | SW205 | SW-TH_MSK12C02 | C431540 | 1 | SHOU HAN(首韩) | MSK12C02
TP4054 | U200 | SOT-23-5_L2.9-W1.6-P0.95-LS2.8-BR | C5381776 | 1 | JSMSEMI(杰盛微) | TP4054
ESP32-S3R8 | U213 | QFN-56_L7.0-W7.0-P0.40-TL-EP4.0 | C2913194 | 1 | ESPRESSIF(乐鑫) | ESP32-S3R8
W25Q128JVPIQ | U214 | WSON-8_L6.0-W5.0-P1.27-BL-EP | C190862 | 1 | WINBOND(华邦) | W25Q128JVPIQ
{ManufacturerPart!} | U216 | WQFN-20_L3.0-W3.0-P0.40-BL-EP1.7 | C962342 | 1 | Everest-semi(顺芯) | ES8311
NS4150B | U217 | MSOP-8_L3.0-W3.0-P0.65-LS5.0-BL | C189961 | 1 | Nsiway(纳芯威) | NS4150B
SZYY0402R | U218 | LED0402-RD_RED | C434445 | 1 | yongyu(永裕光电) | SZYY0402R
ME6217C33M5G | U219 | SOT-23-5_L3.0-W1.7-P0.95-LS2.8-BR | C427602 | 1 | MICRONE(南京微盟) | ME6217C33M5G
PESDNC2FD5VBS | U220 | DFN1006-2L-BI | C110695 | 1 | Prisemi(芯导) | PESDNC2FD5VBS
LIS2DH12TR | U222 | LGA-12_L2.0-W2.0-P0.50-BL | C110926 | 1 | ST(意法半导体) | LIS2DH12TR
USB-TYPE-C-018 | USB2 | usb-c_smd-type-c-31-m-12 | C2927038 | 1 | DEALON(德艺隆) | USB-TYPE-C-018
40MHz | X1 | CRYSTAL-SMD_4P-L3.2-W2.5-BL | C5444549 | 1 | YXC(扬兴晶振) | XL2EL89CPI-111YLC-40M

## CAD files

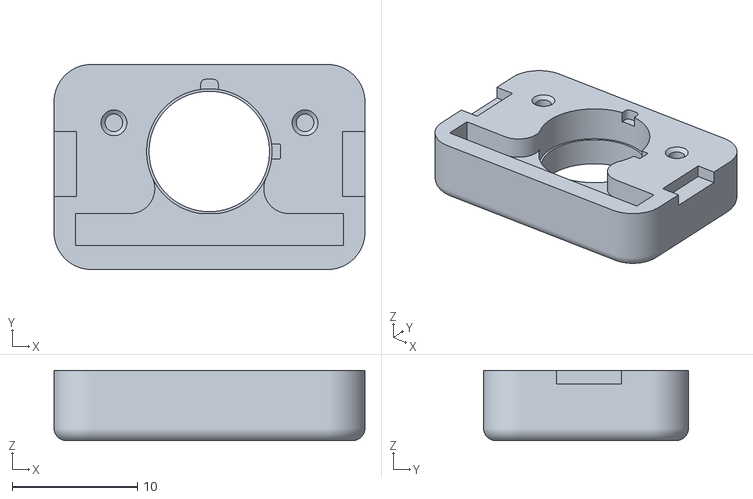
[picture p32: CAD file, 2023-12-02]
extention/MLX90640/stl/top1.1——nosilk.stl
24.8 x 16.4 x 5.60

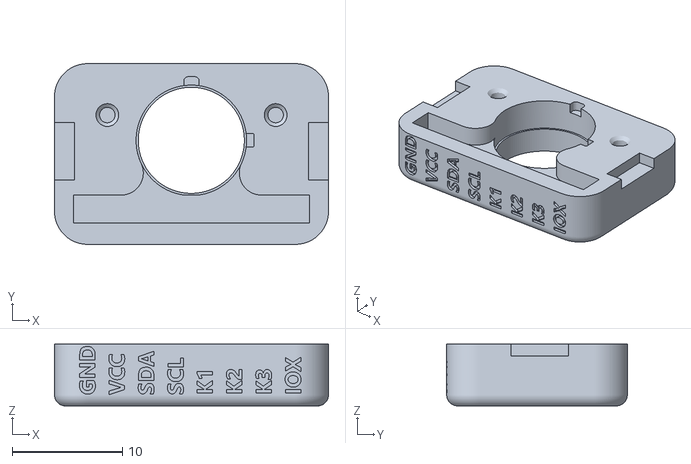
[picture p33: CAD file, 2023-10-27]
extention/MLX90640/stl/top1.1.stl
24.8 x 16.4 x 5.60

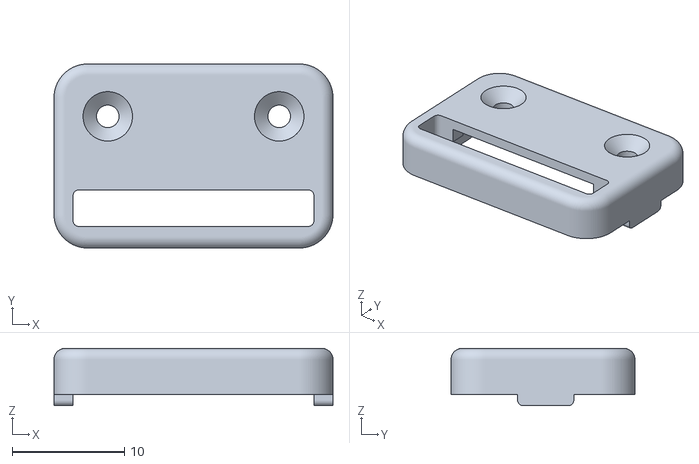
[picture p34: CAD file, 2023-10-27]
extention/MLX90640/stl/bot1.1.stl
24.8 x 16.4 x 5.10

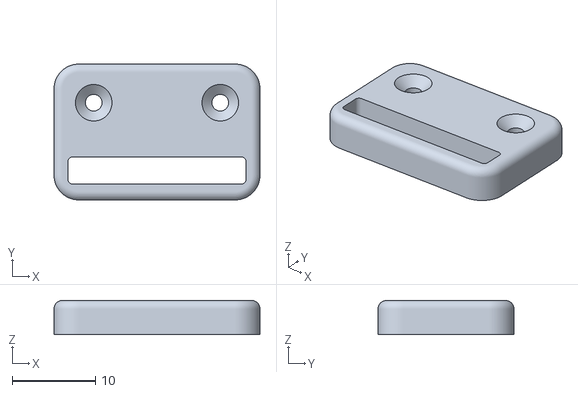
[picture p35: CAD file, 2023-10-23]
extention/MLX90640/stl/bot.stl
24.8 x 16.4 x 4.10

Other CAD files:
hardware/datasheet/0.85_gc9107/ZJY085-1212TBWIG42-2.dwg
hardware/datasheet/0.85_gc9107/ZJY085-1212TBWIG41.dwg
extention/MLX90640/stl/top.stl

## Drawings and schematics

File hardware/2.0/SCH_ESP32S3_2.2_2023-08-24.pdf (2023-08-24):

### Reviewed

### Drawed

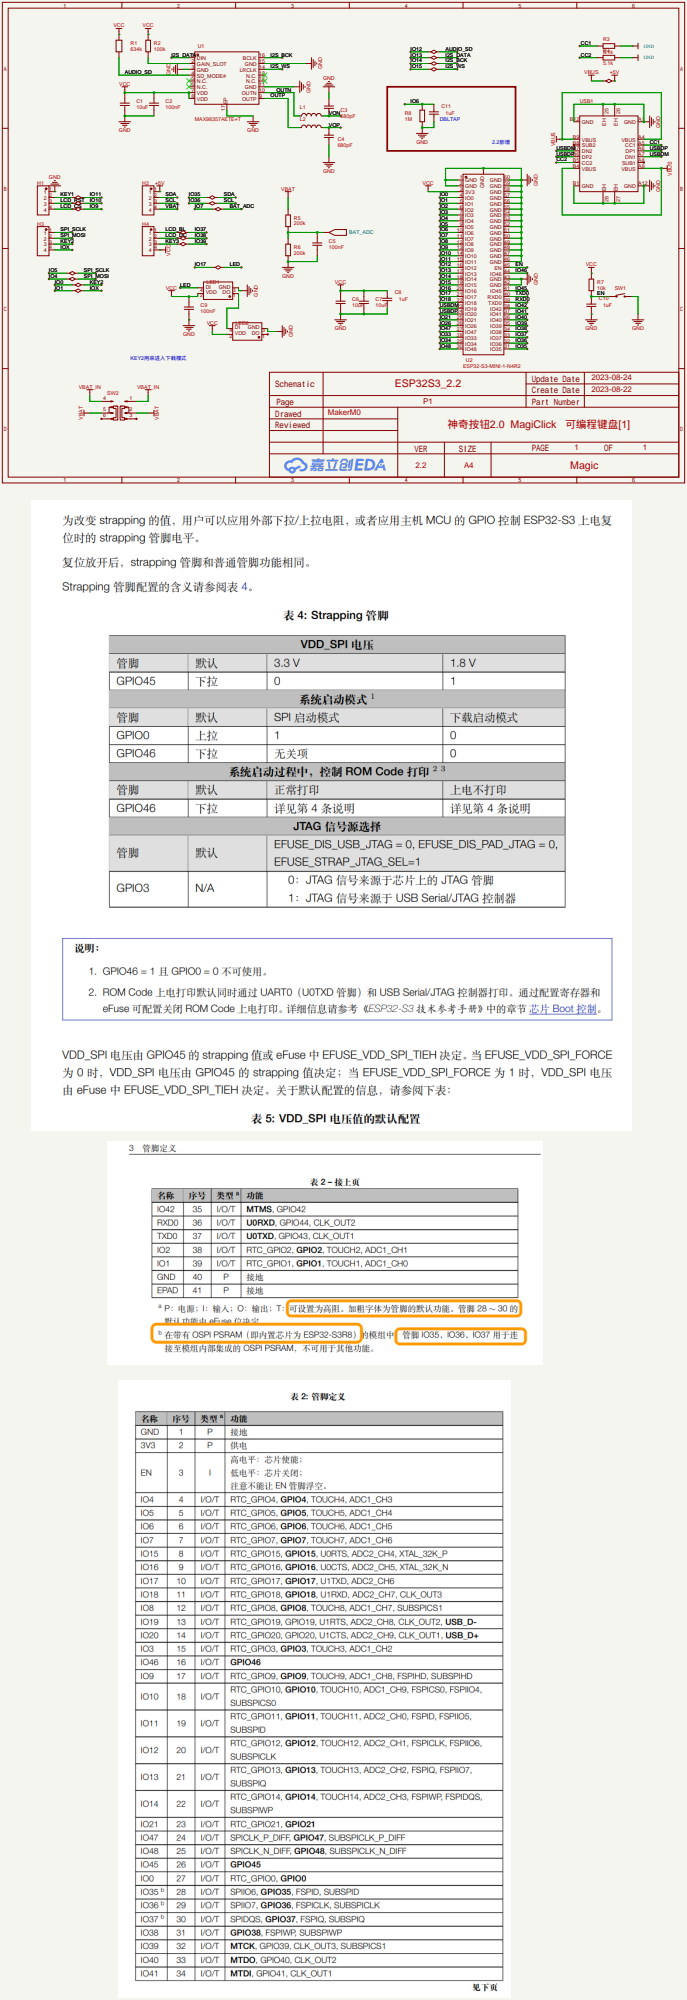
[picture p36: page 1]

OUTN 10 GND 11 N.C. 12 N.C. 13 LRCLK 14 GND 15 BCLK 16

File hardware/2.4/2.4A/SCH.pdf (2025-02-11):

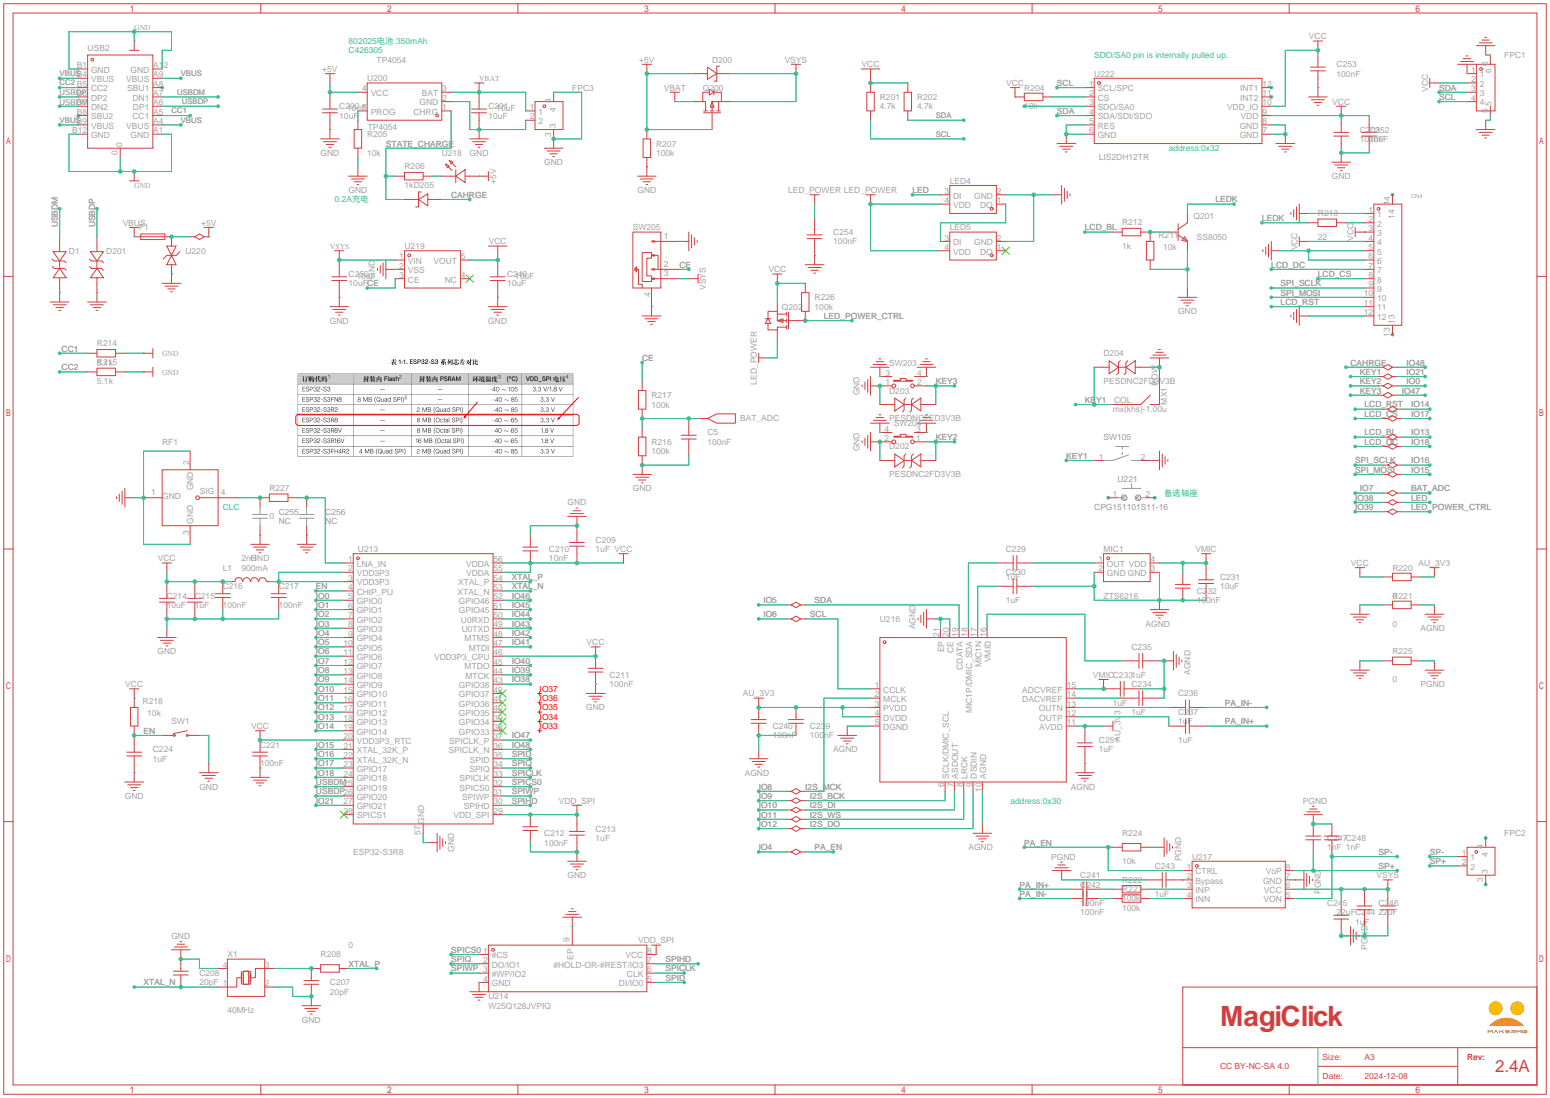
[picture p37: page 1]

GND A1 VBUS A4 CC1 A5 DP1 A6 DN1 A7 SBU1 A8 VBUS A9 GND A12

VMID 16 MIC1N 17 MIC1P/DMIC_SDA 18 CDATA 19 CE 20 EP 21

AVDD 11 OUTP 12 OUTN 13 DACVREF 14 ADCVREF 15

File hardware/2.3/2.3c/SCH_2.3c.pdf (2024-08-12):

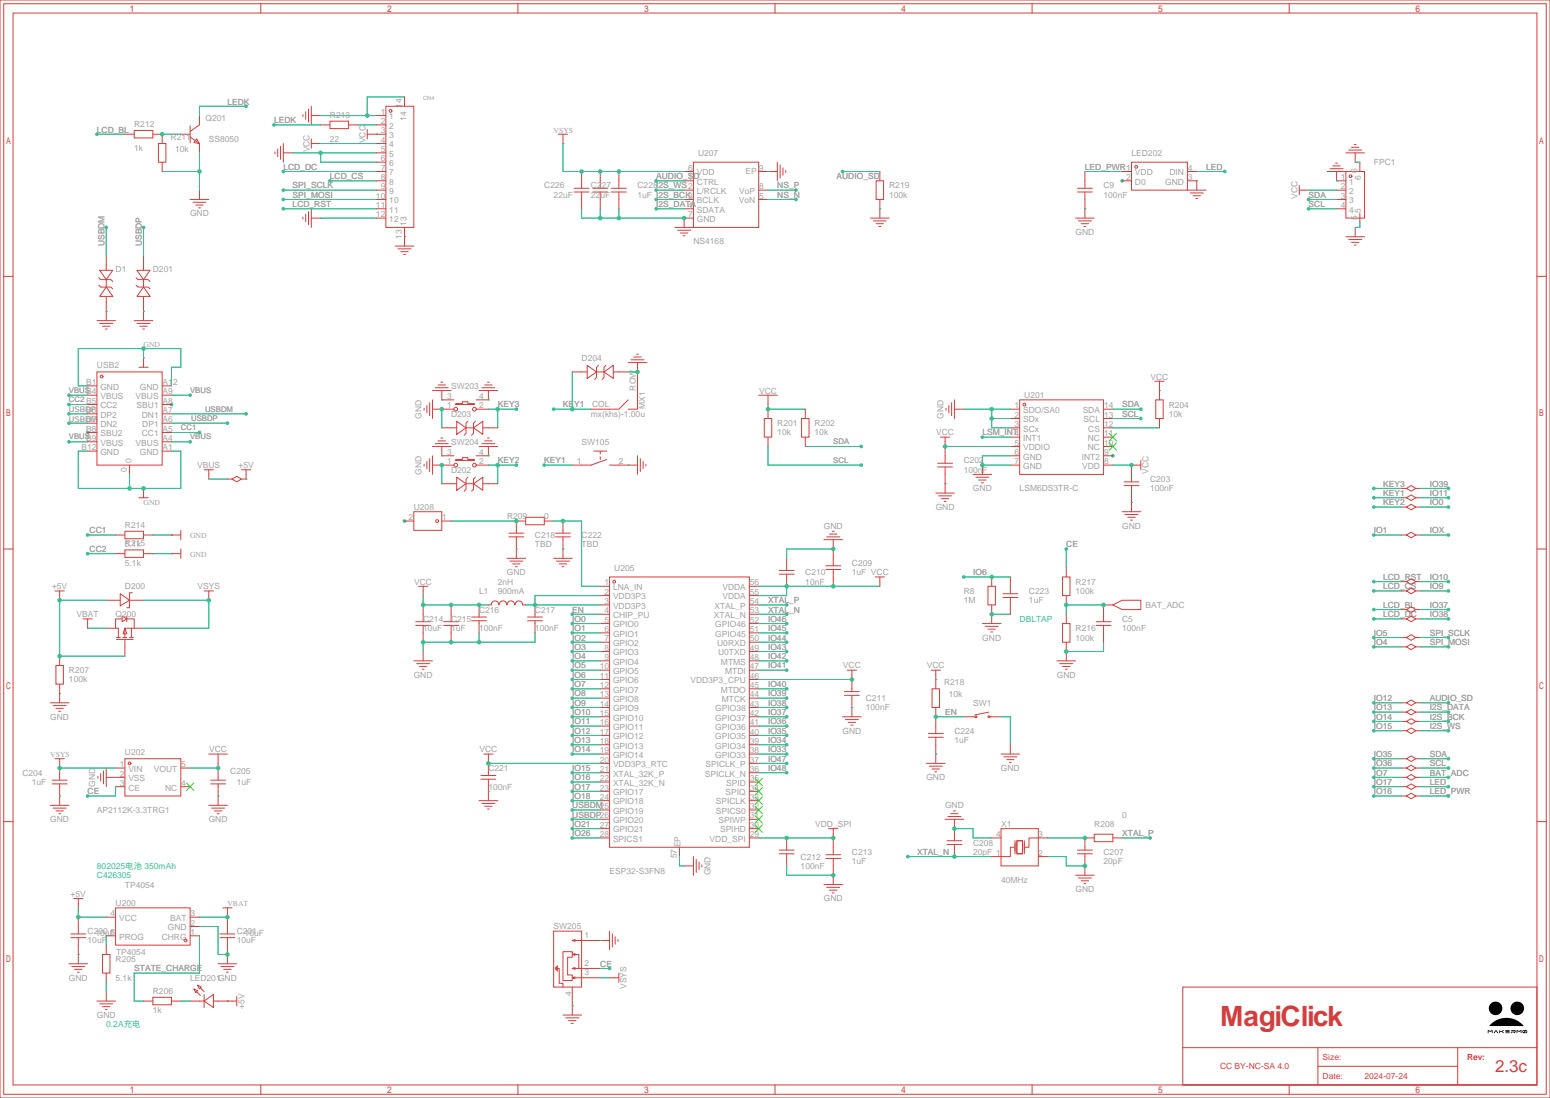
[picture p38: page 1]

GND A1 VBUS A4 CC1 A5 DP1 A6 DN1 A7 SBU1 A8 VBUS A9 GND A12

NC 10 NC 11 CS 12 SCL 13 SDA 14

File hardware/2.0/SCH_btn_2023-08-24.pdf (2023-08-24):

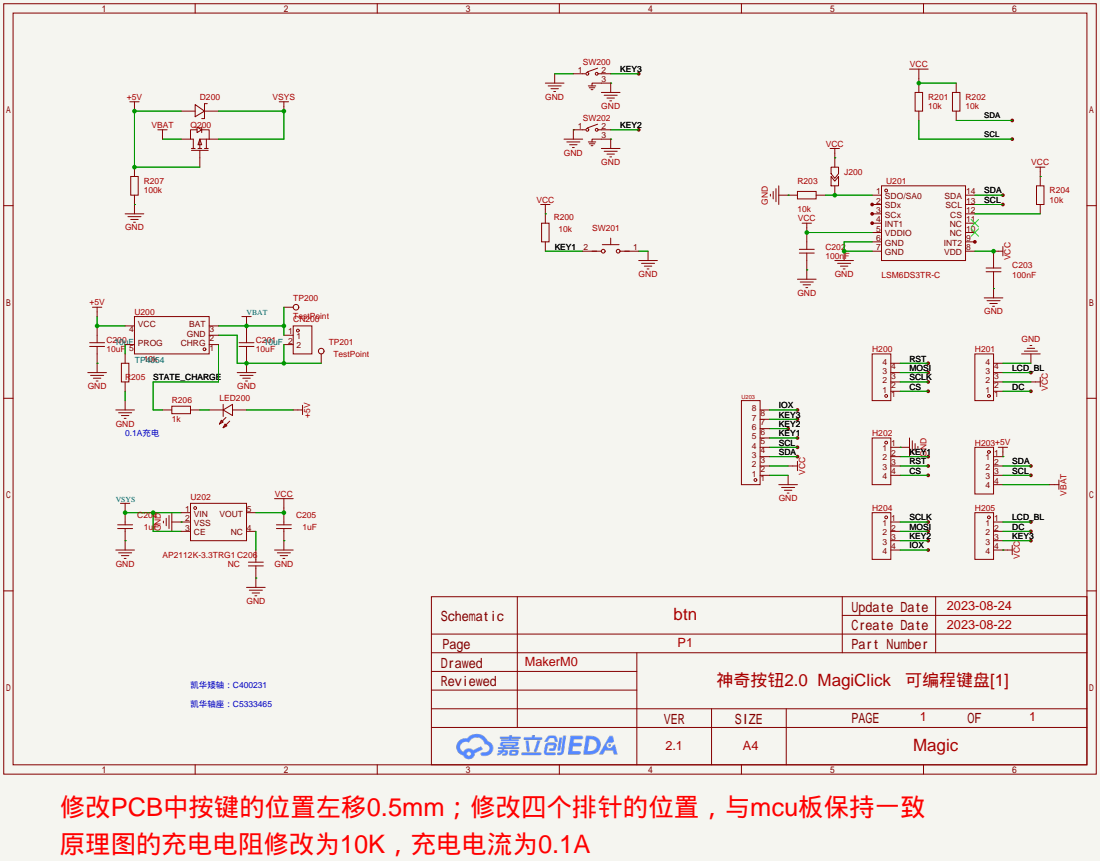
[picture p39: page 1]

NC 10 NC 11 CS 12 SCL 13 SDA 14

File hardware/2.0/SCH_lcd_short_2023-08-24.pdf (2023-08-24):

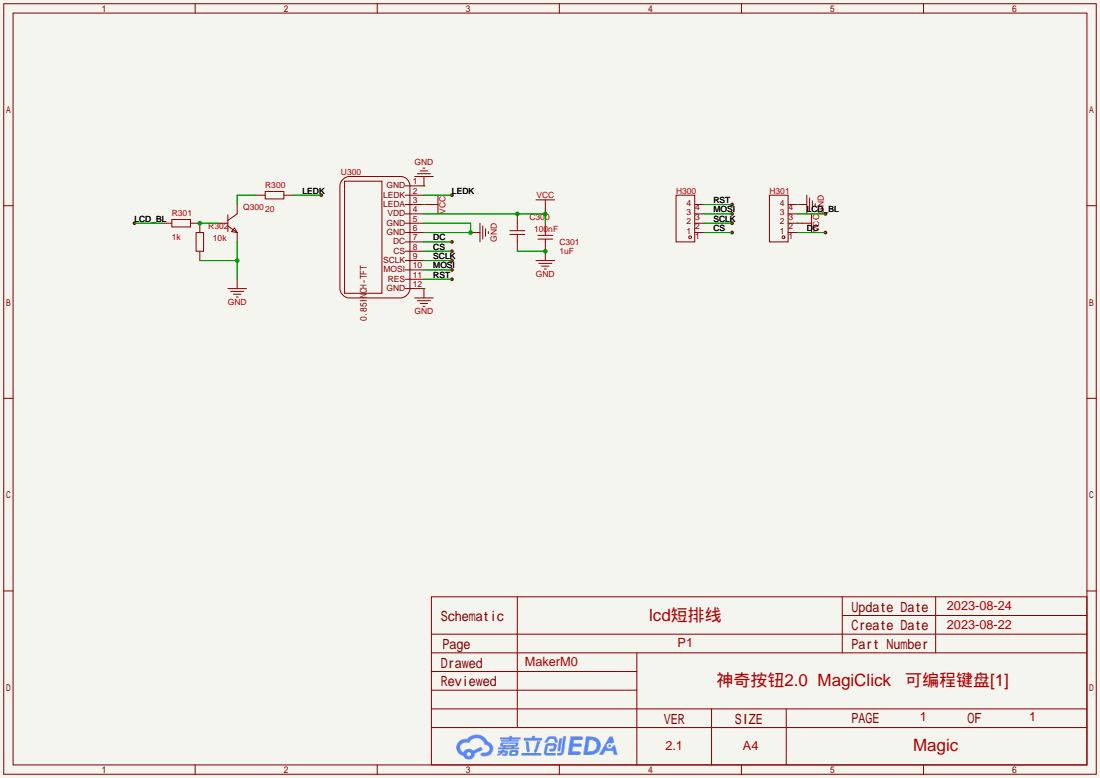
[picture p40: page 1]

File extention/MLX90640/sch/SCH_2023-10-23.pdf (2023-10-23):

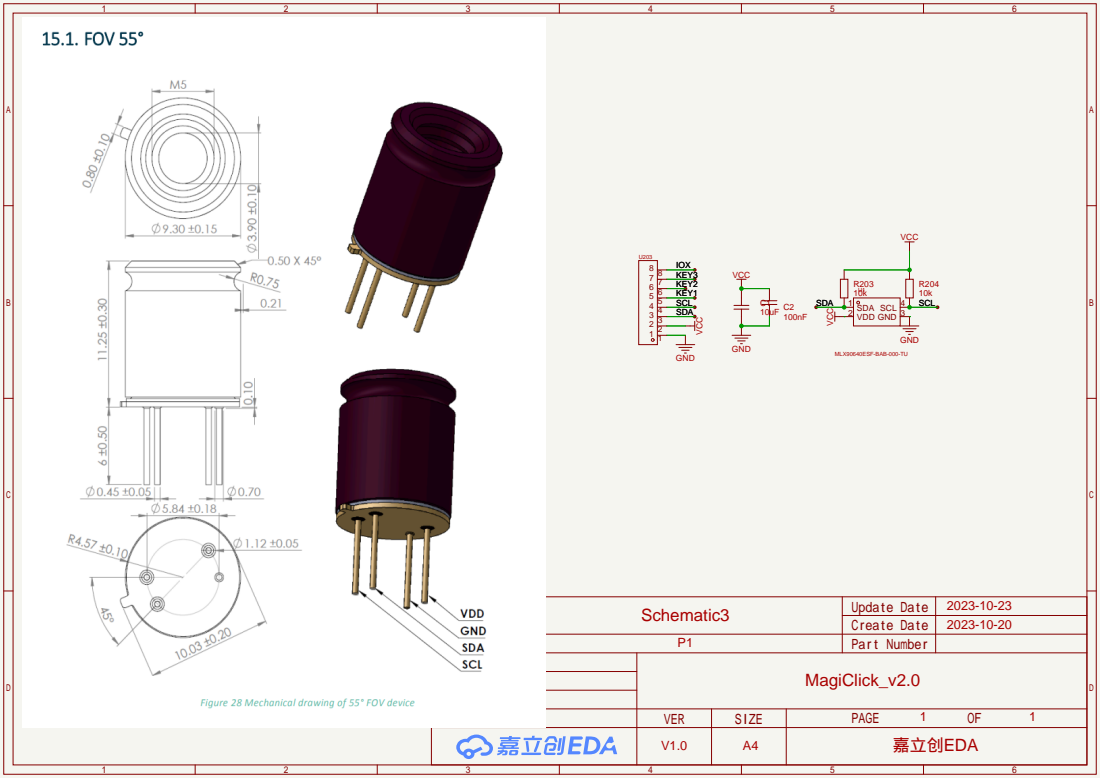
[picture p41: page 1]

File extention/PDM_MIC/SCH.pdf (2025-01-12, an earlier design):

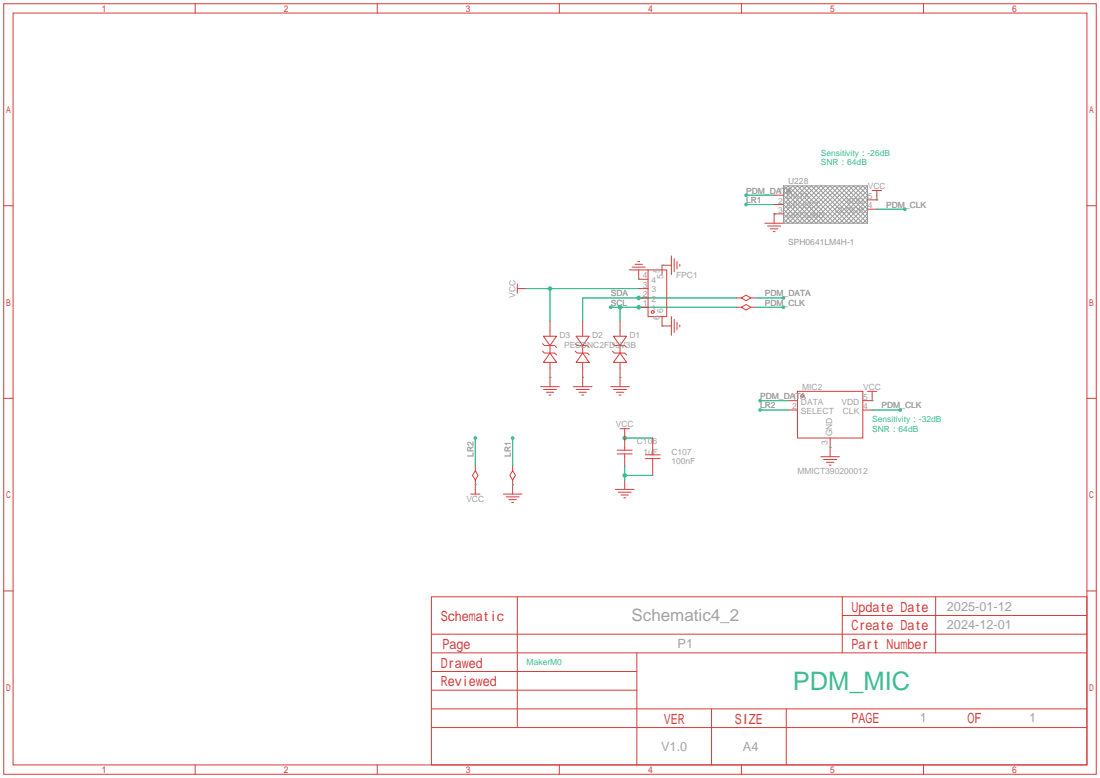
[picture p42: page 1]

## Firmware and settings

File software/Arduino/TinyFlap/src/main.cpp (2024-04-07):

#include <TFT_eSPI.h>
#include <SPI.h>
#include <Ticker.h>
#include <Preferences.h>
//#include "bg.h" // Using background image requires some fiddling with transparent sprites that goes on top of the image.

#define LEFT 0
#define RIGHT 11

#define MODE_1_PROGRESSIVE 1
#define MODE_2_NORMAL 2
#define MODE_3_HARD 3

#define HIGH_SCORES "high_scores"

TFT_eSPI tft = TFT_eSPI();
TFT_eSprite sprite = TFT_eSprite(&tft);
TFT_eSprite logoSpr = TFT_eSprite(&tft);
TFT_eSprite logoBgSpr = TFT_eSprite(&tft);
TFT_eSprite gameOverSpr = TFT_eSprite(&tft);

const int REFRESH_RATE = 20;
unsigned long lastFrame = 0;

bool jumpButtonPressed = false;

float gravity = 0.3;
float jumpStrength = 2.2;

uint16_t modeTextColor ;
uint16_t modeBgColor;

const int BIRD_W = 26;
const int BIRD_H = 20;
uint16_t birdColor;
float birdY = 64;
float birdSpeed = 0;
int birdAngle = 0;

int pipeX = 128;
int pipeGapY = 60;
int pipeGapSize = 40;
int pipeSpeed = 2; // Even numbers only

const int GROUND_STRIPE_HEIGHT = 5;
const int GROUND_STRIPE_WIDTH = 8;
int groundPos = 0;
int groundSpeed = pipeSpeed / 2;

int cloud1X = 20;
int cloud1Y = 20;
int cloud2X = 80;
int cloud2Y = 40;

const float FLAP_INTERVAL = 0.15;
Ticker flapTicker;

int score = 0;
Preferences highScores;
int bestScore = 0;
bool newBestScore = false;

bool ready = false;
bool collision = false;

const int flapStates[] = {1, 2, 3, 2};
const int numFlapStates = sizeof(flapStates) / sizeof(flapStates[0]);
int currentFlapStateIndex = 0;
int flapState = flapStates[currentFlapStateIndex];

const int gameModes[] = {1, 2, 3};
const int numGameModes = sizeof(gameModes) / sizeof(gameModes[0]);
int currentGameModeIndex = 1;
int gameMode = gameModes[currentGameModeIndex];
void setGameMode(int pGameMode);
void flapTick() ;
void setup() {

  pinMode(LEFT, INPUT_PULLUP);
  pinMode(RIGHT, INPUT_PULLUP);

  highScores.begin(HIGH_SCORES, false);

  flapTicker.attach(FLAP_INTERVAL, flapTick);

  tft.init();
  tft.setRotation(2);
  //tft.setSwapBytes(true);

  sprite.createSprite(128,128);
  //sprite.setSwapBytes(true);

  logoBgSpr.createSprite(128, 64);
  logoSpr.createSprite(128, 64);

  setGameMode(gameMode);

}

void setGameMode(int pGameMode) {
  switch(pGameMode) {
    case MODE_1_PROGRESSIVE:
      gravity = 0.3;
      jumpStrength = 2.2;
      pipeGapSize = 160;
      birdColor = TFT_CYAN;
      modeTextColor = TFT_BLACK;
      break;
    case MODE_2_NORMAL:
      gravity = 0.3;
      jumpStrength = 2.2;
      pipeGapSize = 40;
      birdColor = TFT_GOLD;
      modeTextColor = TFT_BLACK;
      break;
    case MODE_3_HARD:
      gravity = 0.4;
      jumpStrength = 4;
      pipeGapSize = 40;
      birdColor = TFT_OLIVE;
      modeTextColor = TFT_WHITE;
      break;
    default:
      ;
  }
  modeBgColor = birdColor;
}

void toggleGameMode() {
  currentGameModeIndex = (currentGameModeIndex + 1) % numGameModes;
  gameMode = gameModes[currentGameModeIndex];

  setGameMode(gameMode);
}

void flapTick() {
  currentFlapStateIndex = (currentFlapStateIndex + 1) % numFlapStates;
  flapState = flapStates[currentFlapStateIndex];
}

TFT_eSprite drawBird() {

  if (collision) {
    birdColor = TFT_LIGHTGREY; // TFT_RED;
  } 

  float x = (BIRD_W / 2) - 4;
  float y = BIRD_H / 2;

  TFT_eSprite birdBackSpr = TFT_eSprite(&tft);
  birdBackSpr.createSprite(BIRD_W + 2, BIRD_H + 2);
  birdBackSpr.fillSprite(TFT_SKYBLUE);

  TFT_eSprite birdSpr = TFT_eSprite(&tft);
  birdSpr.createSprite(BIRD_W, BIRD_H);
  birdSpr.fillSprite(TFT_SKYBLUE);

  // Body and Head
  birdSpr.fillSmoothCircle(x, y, 7, TFT_BLACK); // Body outline
  birdSpr.fillSmoothCircle(x + 5, y, 6, TFT_BLACK); // Head outline
  birdSpr.fillSmoothCircle(x, y, 6, birdColor);
  birdSpr.fillSmoothCircle(x + 5, y, 5, birdColor);

  // Beak
  birdSpr.fillSmoothRoundRect(x + 5, y - 1, 9, 7, 2, TFT_BLACK);
  birdSpr.fillSmoothRoundRect(x + 6, y, 7, 5, 2, TFT_ORANGE);
  int mouthX = (collision) ? x + 7 : x + 8;
  int mouthY = (collision) ? y + 2 : y + 3;
  int mouthW = (collision) ? 6 : 5;
  birdSpr.drawFastHLine(mouthX, mouthY, mouthW, TFT_BLACK);

  // Eye
  birdSpr.fillSmoothCircle(x + 7, y - 3, 3, TFT_BLACK);
  birdSpr.fillSmoothCircle(x + 7, y - 3, 2, TFT_WHITE);
  int eyeBallX = (collision) ? x + 7 : x + 8;
  birdSpr.fillSmoothCircle(eyeBallX, y - 3, 1, TFT_BLACK);

  // Flappy wing
  if (collision) {
    flapState = 2;
  }
  switch(flapState) {
    case 1: // down
      birdSpr.fillSmoothRoundRect(x - 8, y - 1, 10, 7, 2, TFT_BLACK);
      birdSpr.fillSmoothRoundRect(x - 7, y, 8, 5, 2, birdColor);
      break;
    case 2: // neutral
      birdSpr.fillSmoothRoundRect(x - 8, y - 2, 10, 4, 2, TFT_BLACK);
      birdSpr.fillSmoothRoundRect(x - 7, y - 1, 8, 2, 2, birdColor);
      break;
    case 3: // up
      birdSpr.fillSmoothRoundRect(x - 7, y - 4, 10, 6, 2, TFT_BLACK);
      birdSpr.fillSmoothRoundRect(x - 6, y - 3, 8, 4, 2, TFT_PINK);
      break;
    default:
      ; 
  }

  birdSpr.pushRotated(&birdBackSpr, birdAngle, TFT_SKYBLUE);

  return birdBackSpr;
}

void drawCloud(int pX, int pY) {
  uint16_t cloudColor = TFT_WHITE;

  // Draw cloud circles
  sprite.fillCircle(pX, pY, 4, cloudColor);
  sprite.fillCircle(pX + 5, pY + 2, 5, cloudColor);
  sprite.fillCircle(pX + 12, pY, 4, cloudColor);
  sprite.fillCircle(pX + 9, pY - 2, 3, cloudColor);
}

void drawClouds() {
  // Update cloud positions
  cloud1X -= 1;
  cloud2X -= 1;

  if (cloud1X < -16) {
    cloud1X = 128;
    cloud1Y = random(15, 45);
  }

  if (cloud2X < -16) {
    cloud2X = 128;
    cloud2Y = random(15, 45);
  }

  // Draw clouds
  drawCloud(cloud1X, cloud1Y);
  drawCloud(cloud2X, cloud2Y);
}

void drawBackground() {
  // Using background image requires some fiddling with transparent sprites that goes on top of the image.
  return;
  //sprite.pushImage(0, 0, 128, 128, bg);
}

void drawPipes() {
  // Update pipe position
  pipeX -= pipeSpeed;

  if (pipeX < -6) {
    pipeX = 128;
    pipeGapY = random(24, 90);
    score += 1;

    if (gameMode == MODE_1_PROGRESSIVE && pipeGapSize > 40) {
      pipeGapSize -= 1;
    }
  }

  // Draw pipes
  int x = pipeX;
  int gapY = pipeGapY;

  // Upper pipe
  sprite.fillRect(x-1, 0-1, 6+2, (gapY - pipeGapSize / 2) + 2, TFT_BLACK);
  sprite.fillRectHGradient(x, 0, 3, gapY - pipeGapSize / 2, TFT_GREEN, TFT_DARKGREEN);
  sprite.fillRectHGradient(x+3, 0, 3, gapY - pipeGapSize / 2, TFT_DARKGREEN, TFT_GREEN);

  sprite.fillRect((x - 2) - 1, (gapY - pipeGapSize / 2 - 4) - 1, 10 + 2, 4 + 2, TFT_BLACK);
  sprite.fillRect(x - 2, gapY - pipeGapSize / 2 - 4, 10, 4, TFT_GREEN);
  
  // Lower pipe
  sprite.fillRect(x - 1, (gapY + pipeGapSize / 2) - 1, 6 + 2, (128 - (gapY + pipeGapSize / 2)) + 2, TFT_BLACK);
  sprite.fillRectHGradient(x, gapY + pipeGapSize / 2, 3, 128 - (gapY + pipeGapSize / 2), TFT_GREEN, TFT_DARKGREEN);
  sprite.fillRectHGradient(x+3, gapY + pipeGapSize / 2, 3, 128 - (gapY + pipeGapSize / 2), TFT_DARKGREEN, TFT_GREEN);

  sprite.fillRect((x - 2) - 1, (gapY + pipeGapSize / 2) - 1, 10 + 2, 4 + 2, TFT_BLACK);
  sprite.fillRect(x - 2, gapY + pipeGapSize / 2, 10, 4, TFT_GREEN);
}

void drawGround() {
  int screenOffsetX = -groundPos % GROUND_STRIPE_WIDTH * 2;
  int stripeCount = (tft.width() + GROUND_STRIPE_WIDTH) / GROUND_STRIPE_WIDTH + 1;

  sprite.drawFastHLine(0, 128 - 7, 128, TFT_BLACK);
  sprite.drawFastHLine(0, 128 - 6, 128, TFT_BROWN);
  
  // Draw the ground stripes at the current position
  for (int i = 0; i < stripeCount; i++) {
    uint16_t stripeColor = (i % 2 == 0) ? TFT_GREEN : TFT_DARKGREEN;
    int x = i * GROUND_STRIPE_WIDTH + screenOffsetX;
    int y = tft.height() - GROUND_STRIPE_HEIGHT;
    int w = GROUND_STRIPE_WIDTH;
    int h = GROUND_STRIPE_HEIGHT;
    if (x + w > 0 && x < tft.width()) {
      sprite.fillRect(max(x, 0), y, min(w, tft.width() - x), h, stripeColor);
    }
  }

  groundPos += groundSpeed;

  // If the ground has moved past the width of the screen, reset it's position
  if (groundPos >= GROUND_STRIPE_WIDTH) {
    groundPos = 0;
  }
}

void drawScore() {
  sprite.setTextColor(TFT_DARKGREY, TFT_SKYBLUE);
  sprite.setTextSize(2);
  sprite.setTextDatum(TR_DATUM);
  sprite.drawString(String(score), 126, 2);
}

void logo() {
  String logoText = "TinyFlap";
  
  logoBgSpr.fillSprite(TFT_SKYBLUE);
  logoBgSpr.setTextDatum(MC_DATUM);
  logoBgSpr.setTextSize(2);

  logoBgSpr.setTextColor(TFT_DARKGREEN, TFT_SKYBLUE);
  logoBgSpr.drawString(logoText, 66, 33);
  logoBgSpr.pushToSprite(&sprite, 0, 0, TFT_SKYBLUE);

  logoSpr.fillSprite(TFT_SKYBLUE);
  logoSpr.setTextDatum(MC_DATUM);
  logoSpr.setTextSize(2);

  logoSpr.setTextColor(TFT_GREENYELLOW, TFT_SKYBLUE);
  logoSpr.drawString(logoText, 64, 32);
  logoSpr.pushToSprite(&sprite, 0, 0, TFT_SKYBLUE);
}

void drawGetReady() {

  logo();

  sprite.setTextDatum(MC_DATUM);
  sprite.setTextSize(2);

  sprite.setTextColor(TFT_DARKGREY, TFT_SKYBLUE);
  sprite.setTextSize(1);

  sprite.drawString("GET READY!", 64, 64);

  String modeText;
  switch(gameMode) {
    case MODE_1_PROGRESSIVE:
      modeText = "- progressive -";
      break;
    case MODE_2_NORMAL:
      modeText = "- normal -";
      break;
    case MODE_3_HARD:
      modeText = "- hard -";
      break;
    default:
      ;
  }
  sprite.drawString(modeText, 64, 90); // Mode display

  sprite.setTextDatum(BR_DATUM);
  sprite.drawString("START", 124, 117); // Start

  sprite.setTextDatum(BL_DATUM);
  sprite.drawString("MODE", 4, 117); // Mode select
}

void gameOver() {
  gameOverSpr.createSprite(96, 105);

  gameOverSpr.fillSprite(TFT_SKYBLUE);
  gameOverSpr.fillSmoothRoundRect(0, 0, 80, 80, 5, TFT_BLACK); //, TFT_SKYBLUE
  gameOverSpr.fillSmoothRoundRect(1, 1, 78, 78, 4, modeBgColor);

  gameOverSpr.setTextColor(modeTextColor, modeBgColor);
  gameOverSpr.setTextSize(1);
  gameOverSpr.setTextDatum(TC_DATUM);

  gameOverSpr.drawString("SCORE", 40, 10);
  String bestScoreText;
  if (newBestScore) {
    bestScoreText = "NEW BEST";
  } else {
    bestScoreText = "BEST";
  }
  gameOverSpr.drawString(bestScoreText, 40, 45);

  gameOverSpr.setTextSize(2);
  gameOverSpr.drawString(String(score), 40, 22);
  gameOverSpr.drawString(String(bestScore), 40, 57);

  gameOverSpr.setTextColor(TFT_DARKGREY, TFT_SKYBLUE);
  gameOverSpr.setTextSize(1);
  gameOverSpr.setTextDatum(BR_DATUM);
  gameOverSpr.drawString("CONTINUE", 92, 101);

  gameOverSpr.pushSprite(32, 16);
}

void drawFrame() {
  sprite.fillSprite(TFT_SKYBLUE);

  drawBackground();

  drawClouds();

  if (ready) {
    drawPipes();
  }
  
  drawGround();

  if (ready && !collision) {
    drawScore();
  }
  
  drawBird().pushToSprite(&sprite, -1 /*Offset*/, birdY - (BIRD_H / 2), TFT_SKYBLUE);

  if (!ready) {
    drawGetReady();
  }

  sprite.pushSprite(0, 0);
}

int getHighScore() {
  int prefHighScore;
  switch(gameMode) {
    case MODE_1_PROGRESSIVE:
      prefHighScore = highScores.getInt("game_mode_1", 0);
      break;
    case MODE_2_NORMAL:
      prefHighScore = highScores.getInt("game_mode_2", 0);
      break;
    case MODE_3_HARD:
      prefHighScore = highScores.getInt("game_mode_3", 0);
      break;
    default:
      ;
  }
  return prefHighScore;
}

void setHighScore(int pScore) {
  switch(gameMode) {
    case MODE_1_PROGRESSIVE:
      highScores.putInt("game_mode_1", pScore);
      break;
    case MODE_2_NORMAL:
      highScores.putInt("game_mode_2", pScore);
      break;
    case MODE_3_HARD:
      highScores.putInt("game_mode_3", pScore);
      break;
    default:
      ;
  }
  bestScore = pScore;
}

void resetGame() {
  birdY = 64;
  birdSpeed = 0;
  birdAngle = 0;
  pipeX = 128;
  score = 0;
  bestScore = getHighScore();
  newBestScore = false;
  setGameMode(gameMode); // Calling this to reset values in "progressive mode", bird color etc.
  collision = false;
  ready = false;
}

void loop() {

  // Get ready
  while (!ready) {
    drawFrame();
    delay(REFRESH_RATE);

    if (digitalRead(RIGHT) == LOW) {
      resetGame();
      ready = true;
      break;
    }

    if (digitalRead(LEFT) == LOW) {
      toggleGameMode();
      while (digitalRead(LEFT) == LOW) {
        delay(REFRESH_RATE);
      }
    }
  }

  // Collision
  while (collision) {

    if (score > bestScore) {
      newBestScore = true;
      setHighScore(score);
    }

    delay(600);
    gameOver();

    while (jumpButtonPressed) { // Safty to avoid unintended game reset
      if (digitalRead(RIGHT) == HIGH) {
        jumpButtonPressed = false;
      }
    }

    bool halt = true;
    while (halt) {
      while (digitalRead(RIGHT) == LOW) {
        resetGame();
        halt = false;
      }

      // Clear high score
      if (digitalRead(LEFT) == LOW) {
        int resetStart = millis();
        while (digitalRead(LEFT) == LOW) {
          if (millis() - resetStart > 8000) {
            setHighScore(0); // Clearing high score
            gameOver(); // Re-drawing to refresh high score in view
            break;
          }
        }
      }

    }
  }

  // Gameplay
  unsigned long currentMillis = millis();
  if (currentMillis - lastFrame >= REFRESH_RATE) {
    lastFrame = currentMillis;

    // Update bird position and angle
    birdSpeed += gravity;
    birdY += birdSpeed;
    tft.setPivot(12, birdY);
    birdAngle = std::max(-45, std::min(static_cast<int>(birdSpeed * 7), 60));

    // Check for collisions
    if (birdY < -128 /* Top screen is not the limit */ 
      || birdY > 128 - 10 /*Bird*/ - 3 /* Ground */ 
      || (pipeX < 18 && pipeX > 0 && (birdY < pipeGapY - pipeGapSize / 2 
        || birdY > pipeGapY + pipeGapSize / 2))) 
    {
      collision = true;
    }

    drawFrame();

    // Check for input
    if (digitalRead(RIGHT) == LOW) {
      birdSpeed = -jumpStrength;
      birdAngle = -30;
      jumpButtonPressed = true;
    } else {
      jumpButtonPressed = false;
    }

    if (digitalRead(LEFT) == LOW) {
      pipeSpeed = 4;
    } else {
      pipeSpeed = 2;
    }
    groundSpeed = pipeSpeed / 2;
  }
}

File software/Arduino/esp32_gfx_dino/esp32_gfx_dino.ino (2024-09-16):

/*
   Wasm3 - high performance WebAssembly interpreter written in C.
   Copyright © 2021 Volodymyr Shymanskyy, Steven Massey.
   All rights reserved.
*/

#include <Arduino_GFX_Library.h>

#define GFX_BL 37 // default backlight pin, you may replace DF_GFX_BL to actual backlight pin

/* More data bus class: https://github.com/moononournation/Arduino_GFX/wiki/Data-Bus-Class */
Arduino_DataBus *bus = new Arduino_ESP32SPI(38 /* DC */, 9 /* CS */, 5 /* SCK */, 4 /* MOSI */, GFX_NOT_DEFINED /* MISO */ );

/* More display class: https://github.com/moononournation/Arduino_GFX/wiki/Display-Class */

// // for HardWare v2.3
// Arduino_GFX *gfx = new Arduino_NV3023(
//   bus, 10 /* RST */, 0 /* rotation */, false /* IPS */,
//   128 /* width */, 128 /* height */
// );

// for HardWare v2.0
Arduino_GFX *gfx = new Arduino_GC9107(
  bus, 10 /* RST */, 0 /* rotation */, true /* IPS */,
  128 /* width */, 128 /* height */
);

#include <wasm3.h>
#define NATIVE_STACK_SIZE   (32*1024)

#define BUTTON_UP           11
#define BUTTON_DOWN         0
#define BUTTON_ROTATION     39

/*
   Dino game by by Ben Smith (binji)
     https://github.com/binji/raw-wasm/tree/master/dino
   To build:
     export PATH=/opt/wasp/build/src/tools:$PATH
     wasp wat2wasm --enable-numeric-values -o dino.wasm dino.wat
     xxd -iC dino.wasm > dino.wasm.h

   Note: In Arduino IDE, select Tools->Optimize->Faster (-O3)
*/
#include "dino.wasm.h"

/*
   Engine start, liftoff!
*/

#define FATAL(func, msg) { Serial.print("Fatal: " func " "); Serial.println(msg); while(1) { delay(100); } }
#define TSTART()         { tstart = micros(); }
#define TFINISH(s)       { tend = micros(); Serial.print(s " in "); Serial.print(tend-tstart); Serial.println(" us"); }

// The Math.random() function returns a floating-point,
// pseudo-random number in the range 0 to less than 1
m3ApiRawFunction(Math_random)
{
  m3ApiReturnType (float)
  float r = (float)random(INT_MAX) / INT_MAX;

  m3ApiReturn(r);
}

// Memcpy is generic, and much faster in native code
m3ApiRawFunction(Dino_memcpy)
{
  m3ApiGetArgMem  (uint8_t *, dst)
  m3ApiGetArgMem  (uint8_t *, src)
  m3ApiGetArgMem  (uint8_t *, dstend)

  do {
    *dst++ = *src++;
  } while (dst < dstend);

  m3ApiSuccess();
}

IM3Environment  env;
IM3Runtime      runtime;
IM3Module       module;
IM3Function     func_run;
uint8_t*        mem;

void load_wasm()
{
  M3Result result = m3Err_none;

  if (!env) {
    env = m3_NewEnvironment ();
    if (!env) FATAL("NewEnvironment", "failed");
  }

  m3_FreeRuntime(runtime);

  runtime = m3_NewRuntime (env, 1024, NULL);
  if (!runtime) FATAL("NewRuntime", "failed");

  result = m3_ParseModule (env, &module, dino_wasm, sizeof(dino_wasm));
  if (result) FATAL("ParseModule", result);

  result = m3_LoadModule (runtime, module);
  if (result) FATAL("LoadModule", result);

  m3_LinkRawFunction (module, "Math",   "random",     "f()",      &Math_random);
  m3_LinkRawFunction (module, "Dino",   "memcpy",     "v(iii)",   &Dino_memcpy);

  mem = m3_GetMemory (runtime, NULL, 0);
  if (!mem) FATAL("GetMemory", "failed");

  result = m3_FindFunction (&func_run, runtime, "run");
  if (result) FATAL("FindFunction", result);
}

void init_device()
{
  pinMode(BUTTON_UP,   INPUT_PULLUP);
  pinMode(BUTTON_DOWN, INPUT_PULLUP);

  pinMode(BUTTON_ROTATION, INPUT_PULLUP);

  // Try to randomize seed
  randomSeed((analogRead(7) << 16) + analogRead(7));
  Serial.print("Random: 0x"); Serial.println(random(INT_MAX), HEX);
}

void setup()
{
  Serial.begin(115200);

#ifdef GFX_EXTRA_PRE_INIT
  GFX_EXTRA_PRE_INIT();
#endif

  // Init Display
  if (!gfx->begin())
  {
    Serial.println("gfx->begin() failed!");
  }
  gfx->fillScreen(WHITE);

#ifdef GFX_BL
  pinMode(GFX_BL, OUTPUT);
  digitalWrite(GFX_BL, HIGH);
#endif

  Serial.println("\nWasm3 v" M3_VERSION " (" M3_ARCH "), build " __DATE__ " " __TIME__);

  uint32_t tend, tstart;
  TSTART();
  init_device();
  TFINISH("Device init");

  TSTART();
  load_wasm();
  TFINISH("Wasm3 init");

  Serial.println("Running WebAssembly...");

  xTaskCreate(&wasm_task, "wasm3", NATIVE_STACK_SIZE, NULL, 5, NULL);
}

void wasm_task(void*)
{
  M3Result result;
  uint64_t last_fps_print = 0;
  uint8_t r=0;

  while (true) {
    const uint64_t framestart = micros();

    // Process inputs
    uint32_t* input = (uint32_t*)(mem + 0x0000);
    *input = 0;
    if (LOW == digitalRead(BUTTON_UP)) {
      *input |= 0x1;
    }
    if (LOW == digitalRead(BUTTON_DOWN)) {
      *input |= 0x2;
    }

    if (LOW == digitalRead(BUTTON_ROTATION)) {
      delay(50);
      if (LOW == digitalRead(BUTTON_ROTATION))
      {
        r++;
        gfx->setRotation(r%4);
        gfx->fillScreen(WHITE);
      
      delay(100);
      }
    }


    // Render frame
    result = m3_CallV (func_run);
    if (result) break;

    // Output to display (Big Endian)
    gfx->draw16bitRGBBitmap(0, 127 - 75, (uint16_t*)(mem + 0x5000), 128, 75);

    const uint64_t frametime = micros() - framestart;
    const uint32_t target_frametime = 1000000 / 50;
    if (target_frametime > frametime) {
      delay((target_frametime - frametime) / 1000);
    }
    if (framestart - last_fps_print > 1000000) {
      Serial.print("FPS: "); Serial.println((uint32_t)(1000000 / frametime));
      last_fps_print = framestart;
    }
  }

  if (result != m3Err_none) {
    M3ErrorInfo info;
    m3_GetErrorInfo (runtime, &info);
    Serial.print("Error: ");
    Serial.print(result);
    Serial.print(" (");
    Serial.print(info.message);
    Serial.println(")");
    if (info.file && strlen(info.file) && info.line) {
      Serial.print("At ");
      Serial.print(info.file);
      Serial.print(":");
      Serial.println(info.line);
    }
  }
}

void loop()
{
  delay(100);
}

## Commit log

2023-08-24 upload hw
    [BOM_整体_2023-08-22.xlsx, PickAndPlace_整体_2023-08-22.xlsx, 压板.stl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]
2023-08-24 修改协议
2023-09-03 upload hardware
    [PickAndPlace_整体_2023-08-22.xlsx, 压板.stl, 压板1.05.stl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]
2023-09-07 update stl
    [压板1.05.stl, 底盖_螺母1.6_兼容.stl]
2023-09-30 add stl
    [压板-1.05_new.stl, 外壳_螺母1.6-1.3螺母高.stl, 盖板-加厚.stl]
2023-10-01 add circuitpython download url
2023-10-04 add mpy-lvgl
    from jd3096
    [外壳_螺母1.6_拼版优化.stl]
2023-10-08 add battery.py
2023-10-08 Update battery.py
    fix
2023-10-19 add pin map
    [pin.xlsx]
2023-10-23 add ext mlx90640
    [bot.stl, top.stl]
2023-10-27 update mlx 1.1 pcb&stl&py
    Adjust the sensor orientation on the PCB.
    The code comes from adafruit, and no interpolation is done yet
    [bot1.1.stl, top1.1.stl]
2023-10-29 add support ESP32-S3-MINI-1-N8
2023-12-06 add led
2024-04-19 add pcb v2.3b
    [BOM_s3_2.3b_btn_5_2024-04-19.xlsx, BOM_整体_2023-08-22.xlsx, PickAndPlace_btn_5_2024-04-19.xlsx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]
2024-08-12 add 2.3c
    [压板-1.05_new.stl, 压板1.05.stl, 压板1.2.stl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]
2024-09-19 add hw 2.3c
    [BOM_2.3c.xlsx, PickAndPlace_2.3c.xlsx]
2024-12-02 add datasheet
    display
    [ZJY085-1212TBWIG41.dwg, ZJY085-1212TBWIG42-2.dwg]
2025-01-12 add pdm_mic support
    [BOM.xlsx]
2025-01-12 add pdm gerber
2025-02-11 add Ver 2.4
    [BOM.xlsx, BOM_2.3c.xlsx, BOM_s3_2.3b_btn_5_2024-04-23.xlsx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]
2025-04-01 add new version
    new lcd driver gc9107
2026-02-17 add tft_espi setup for v2.5 pcb
